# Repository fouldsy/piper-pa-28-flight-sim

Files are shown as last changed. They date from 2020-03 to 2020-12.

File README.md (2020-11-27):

# Piper PA-28 project

After many years of flight simming, I'm currently building a flight simulator using the cockpit from a 1975 Piper PA-28-151 interfaced to X-Plane 11 using AirManager.

For more information, see [the Piper PA-28 project website](https://fouldsy.github.io/piper-pa-28-flight-sim/index.html)

The following flight was taken over the San Juan Islands in X-Plane 11:

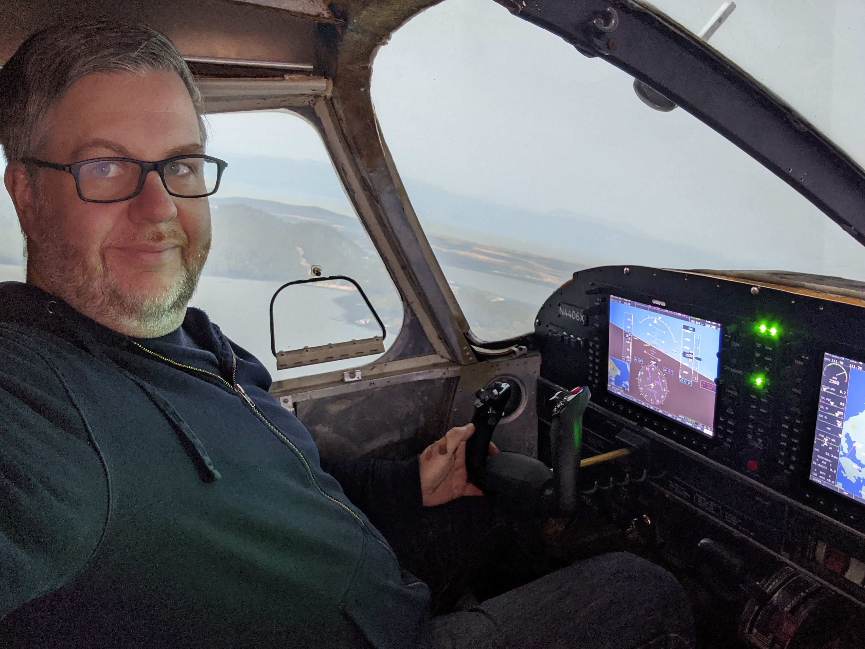
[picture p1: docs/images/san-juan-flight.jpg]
Flight over the San Juan Islands


Current view of the inside of the cockpit:

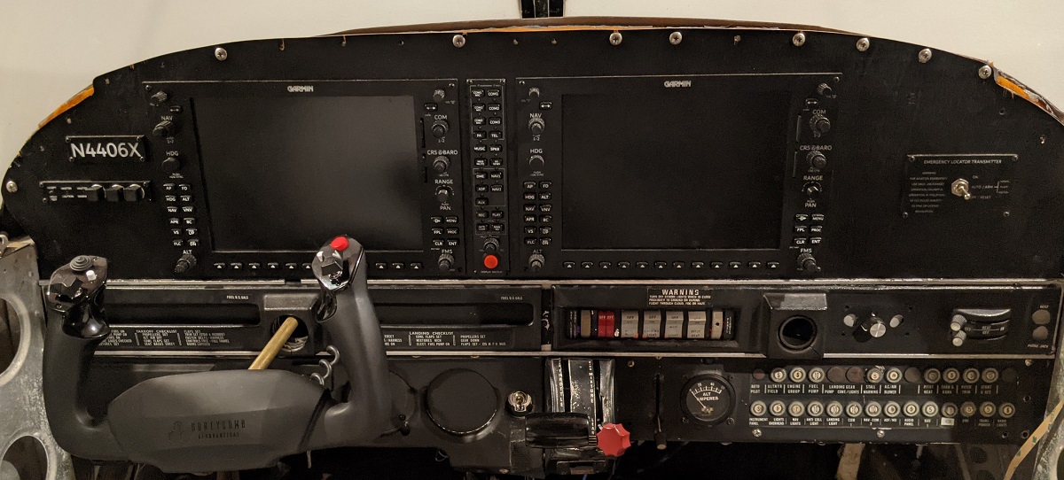
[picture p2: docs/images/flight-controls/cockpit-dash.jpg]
Inside the cockpit


Fully functional controls:

* Home made laser cut and 3D printed Garmin G1000 PFD, audio panel, and MFD
* Honeycomb Aeronautical Alpha yoke with shaft extension
* 3D printed fuel selector valve
* 5-position ignition switch

The following OEM hardware is also fully functional within the flight simulator:

* Switch panel
* Throttle and mixture controls
* Elevator trim wheel
* Flaps lever
* Parking brake
* Annunciator panel

Current view of outside of the cockpit:

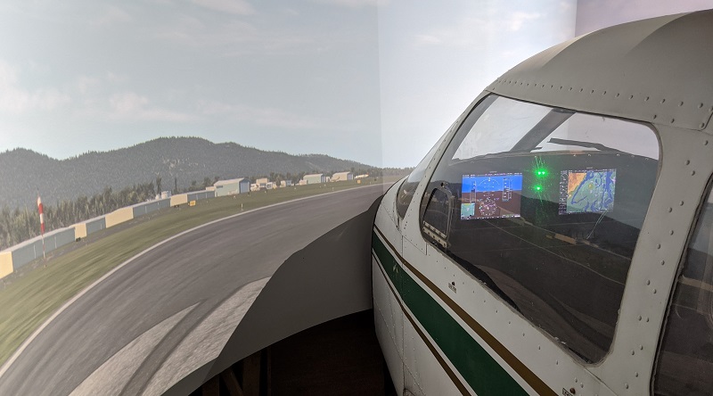
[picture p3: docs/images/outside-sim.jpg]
Outside the cockpit


The 12ft diameter 180 degree curved screen uses two Optoma GT1080 short-throw projectors warped using [Immersive Display PRO from  Fly Elise-ng](https://fly.elise-ng.net/immersive-display-pro/). The screen surface is painted a light grey.

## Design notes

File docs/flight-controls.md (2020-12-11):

# Flight controls

Where possible, I've tried to use OEM parts. The cockpit itself is a Piper PA-218-151, but I've given myself a little wiggle room since in X-Plane 11 I'm flying a PA-28-161.

Cockit panel

Associated 3D components for adapting the OEM flight controls at [https://www.thingiverse.com/thing:4681780](https://www.thingiverse.com/thing:4681780).

## Flight yoke

The primary non-OEM part in the whole cockpit (aside from the G1000 units) is the yoke. I looked at ways to use an OEM yoke with a home-built control system, or to retrofit an OEM yoke onto a commercial USB yoke.

In the end, I went with the [Honeycomb Aeronautical Alpha yoke](https://flyhoneycomb.com/collections/honeycomb-flight-sim-hardware/products/alpha-flight-controls). I like the idea of having some additional controls on the yoke that could be mapped into the game if I wanted to change the views or for ATC communication, etc.

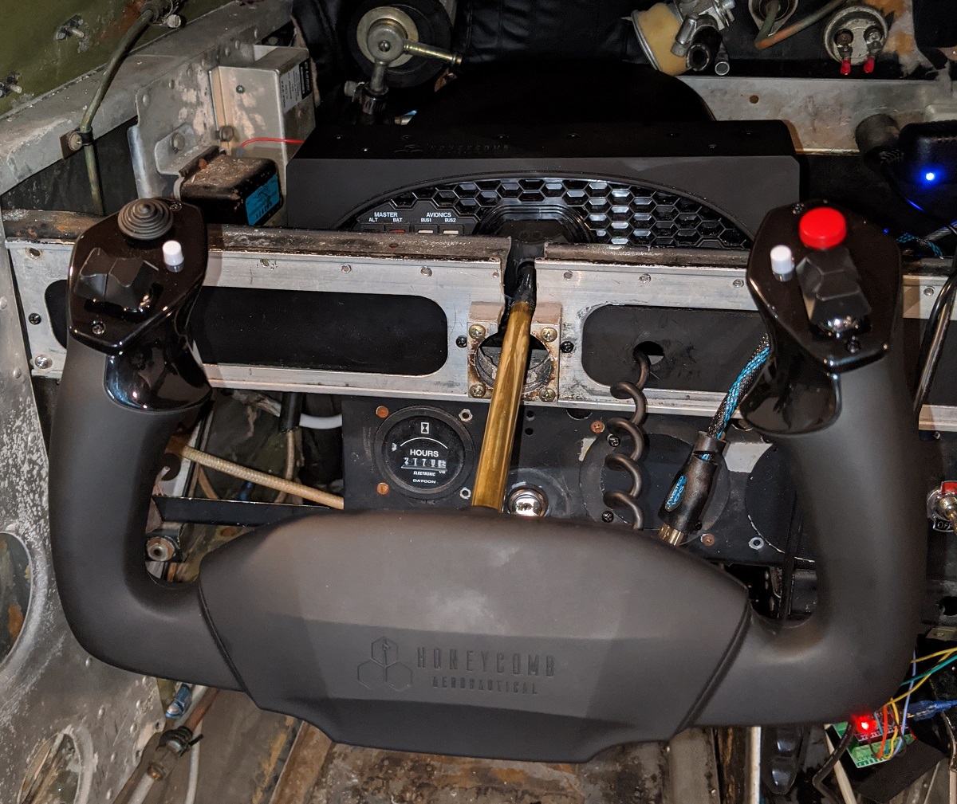
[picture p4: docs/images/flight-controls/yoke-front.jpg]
Extended shaft on Honeycomb Alpha yoke


The shaft of the yoke had to be extended for enough travel since it's mounted behind the panel. Without extending the yoke, my hands were so close to the G1000 units it was almost unusable. Thankfully, the Honeycomb yoke doesn't have wires that run through the shaft itself like some other yokes do. Instead, it's a solid steel shaft. I cut the steel shaft then used brass tube that I could slide over the existing steel shaft. This brass tube is glued with J-B Weld.

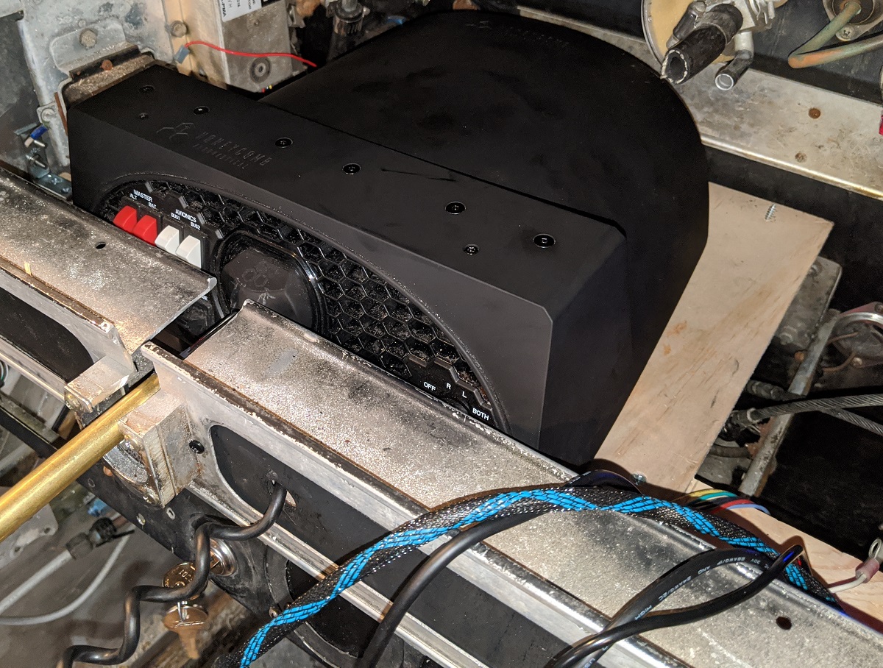
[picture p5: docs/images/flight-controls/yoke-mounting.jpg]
Mounting platform behind the dash for the Honeycomb Alpha yoke


Mounting the yoke was tough. There's very little room between the cockpit panel and the firewall, and the Honeycomb yoke only *just* fits in there. I made a platform for the yoke to attach to with its screw clamps. The platform is attached into the firewall and the sides of the cockpit with metal brackets.

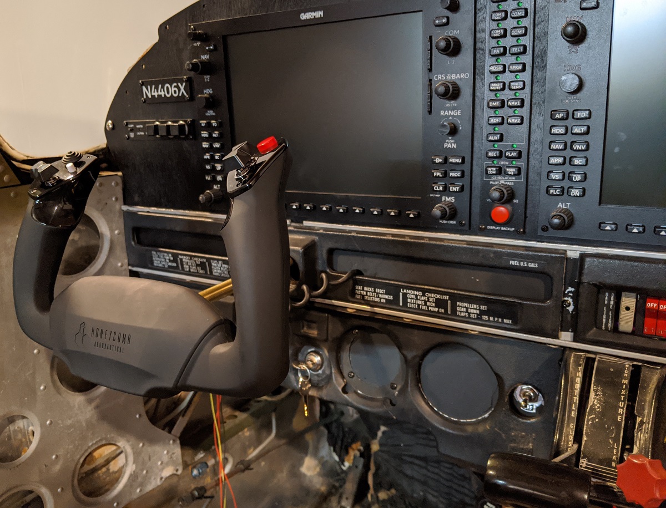
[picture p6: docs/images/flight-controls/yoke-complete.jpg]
Finished install of the Honeycomb Alpha yoke


Once all the panels are put back in place, it looks pretty good, and is solid enough that the yoke doesn't move around on the mounting platform. Yes, the switches and ignition on the Honeycomb yoke can't be used, but I have the real gear for that elsewhere in the cockpit anyway.

## Switch panel

The switch panel I don't *think* is from an actual PA-28-151, but it's mainly the exterior lighting controls that vary slightly between models. This is close enough for what I want.

All the original switches are used, though the wiring has been replaced to run through an Arduino Nano which then connects to Air Manager.

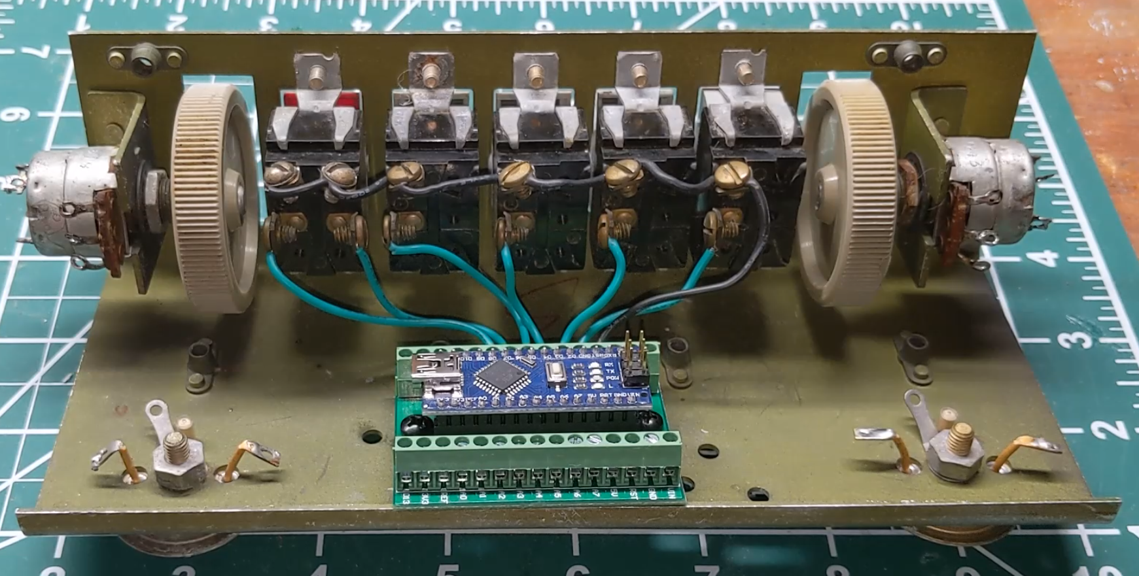
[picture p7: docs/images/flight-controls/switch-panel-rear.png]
Rear of the switch panel


The right-hand side rotating switch has also been connected to an LED strip controller (not shown in the photo) that will be used for the glare shield dash lights. A small circuit was included with the LED controller, so I rewired it from the built-in rotating switch to use this rotary knob on the switch panel. Works well. The LEDs are currently on the plastic spool ready for the glareshield to be built and installed, but the rotating switch does raise and lower the brightness of the LEDs.

## Throttle and mixture controls

The throttle and mixture levels were the first challenging OEM part I converted for use with the flight sim. Unlike a sliding potentiometer that could be used in Cessna flight sim, the Piper PA-28 use a rotating lever for both the throttle and mixture controls. These controls came with the cockpit, and I really wanted to use them.

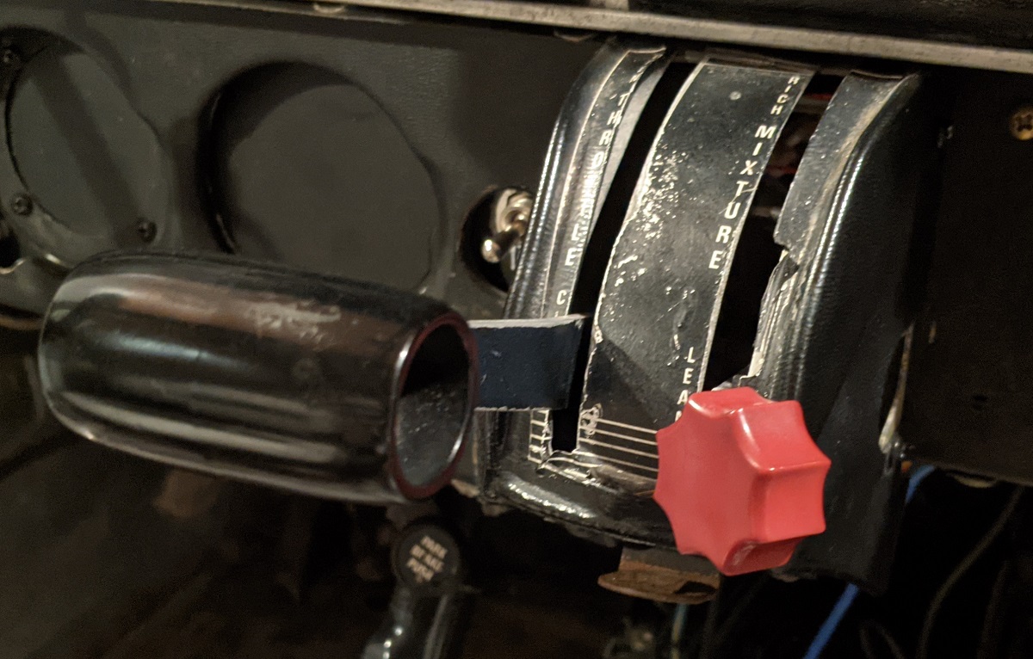
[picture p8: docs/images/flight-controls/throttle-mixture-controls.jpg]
Throttle and mixture controls


They work quite simply, after much thinking about ways to convert the motion for use with flight sim. The bolts for the levers were removed, and a potentiometer is attached to the metal brackets. The shaft of the potentiometer replaces the bolt, so the lever can continue to pivot. An adapter was designed and 3D printed that is glued to the lever and into the potentiometer. When the throttle or mixture lever moves, the potentiometer rotates with it.

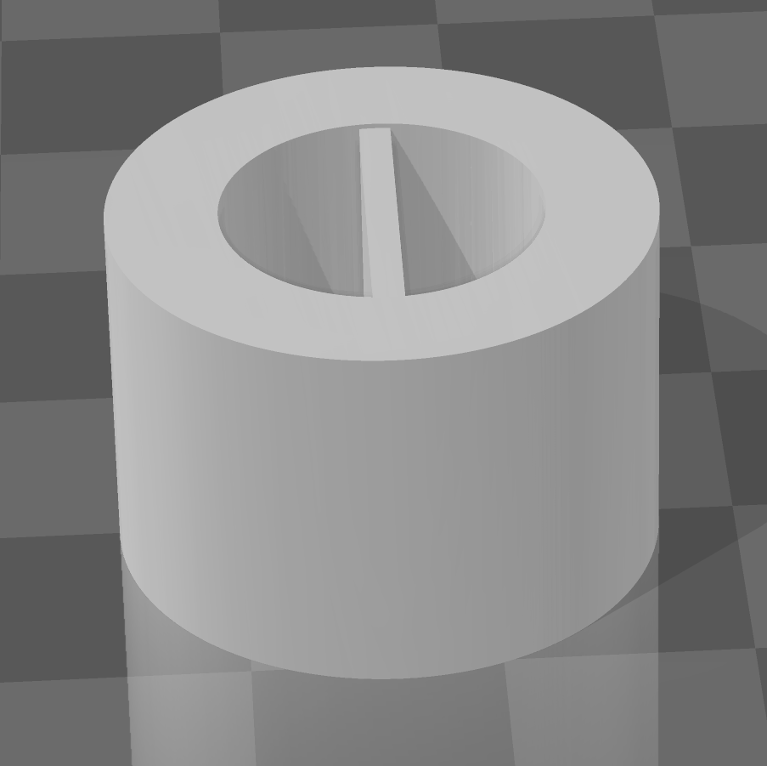
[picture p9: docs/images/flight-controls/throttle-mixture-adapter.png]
3D printed throttle and mixture adapter


As the potentiometer doens't move the whole range of motion, some math is done in Air Manager to multiply the potentiometer value into a ratio for use with the throttle and mixture controls. It doesn't give super precise change of throttle or mixture throughout the movement of a lever, but it's close enough for what I use in the flight sim.

## Flaps lever

The flaps lever was another challenging OEM conversion. Again, unlike a Cessna that has a flaps switch that's easier to model, the PA-28 uses a lever, similar to handbrake lever in a car. I worked through some ideas of trying to use contact points as the lever moved and locked into each position, but ended up with desiging and 3D printing an adapter for the end of the bolt that holds the lever in place.

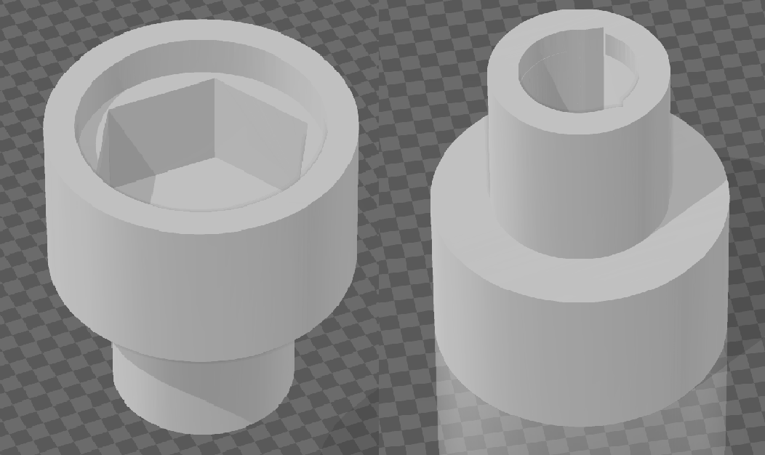
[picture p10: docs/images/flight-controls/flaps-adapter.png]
3D printed flaps lever adapter


The bolt was attached to the lever with JB Weld, rather than letting it simply be a pivot point. When the flaps handle is raised or lowered, the bolt rotates with it. The 3D printed adapter on the bolt head then turns a rotary encoder up or down accordingly. There's another 3D printed mount for the rotary encoder to attach it to the outside of the flaps lever base, which can be seen in the following photo:

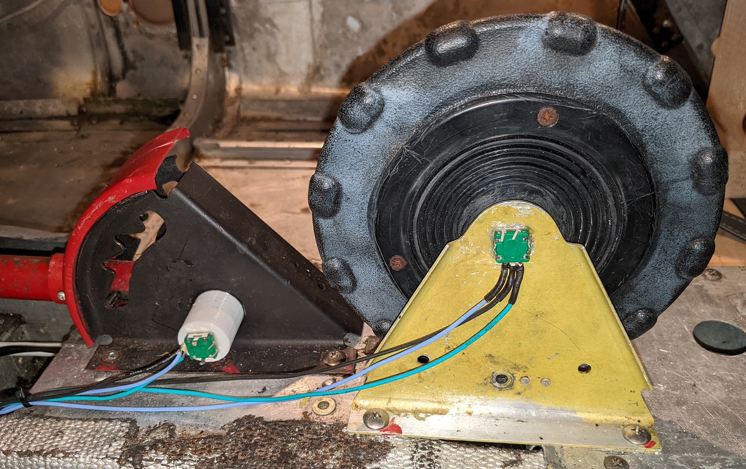
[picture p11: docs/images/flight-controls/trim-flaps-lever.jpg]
Flaps lever and trim wheel


The fun part was then translating this into positions of the flaps lever. There's some logic in the Air Manager Lua script that checks the time interval for the rotary encoder movement. Air Manager ignores rotary encoder changes for 1 second after the first motion.

What does this mean in practice?

* When you raise the flaps lever, the rotary encoder is first engaged.
* Air Manager sees the rotation, so raises the flaps in the flight sim.
* The flaps lever is physically locked in place and the rotary encoder stops moving.
* The raising of the flaps is one fluid motion, so Air Manager is waiting for a 1 second interval where the rotary encoder is now longer moving.
* At that point, Air Manager assumes any additional motion it detects is because you're again raising the flaps, or lowering them.

This all works well in practice, as you wouldn't typically raise flaps more than one notch at a time. The flight sim isn't detecting position 1, 2, or 3 for the flaps, rather it's just a flaps up or down command. When you land and are rolling out, I just need to make sure I lower one notch at a time with a couple of seconds break in between each lowering of flaps.

## Trim wheel

The trim wheel uses a similar approach as the throttle and mixture controls. A rotary encoder is used instead of a bolt, with the shaft of the rotary encoder inserted part way into the trim wheel. A 3D printed adapter is inserted through the rest of the trim wheel and glued in place so it rotates with the trim wheel. The adapter then causes the rotary encoder to turn as the trim wheel does.

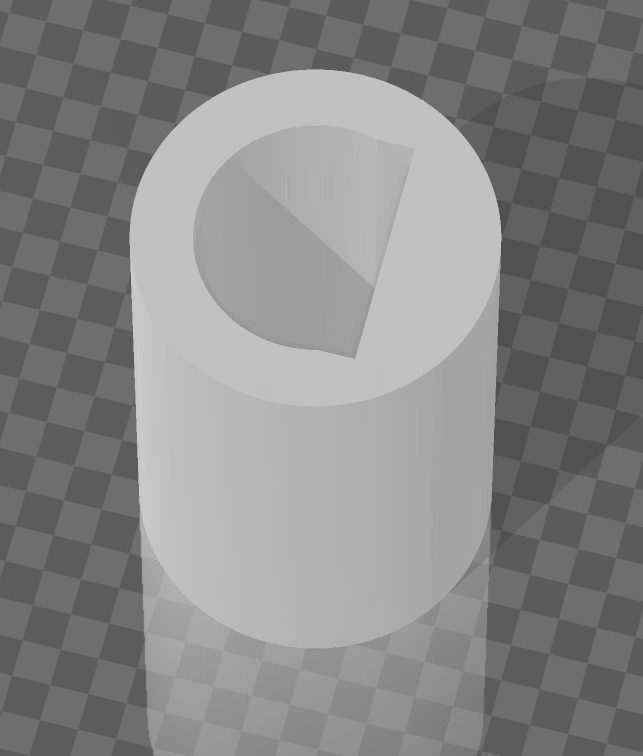
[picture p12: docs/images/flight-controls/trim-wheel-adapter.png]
3D printed trim wheel adapter


I had looked at 3D printing a trim wheel, as I found a suitable model online, but since almost everything else was OEM, I figured it made sense to get an OEM trim wheel, too.

Air Manager then trims the airplane up or down based on the rotary encoder motion. There's no additional logic required like with the flaps lever.

## Parking brake

The parking brake was the last thing I worked on. I tried a couple of different approaches, but came back to the tried and true approach of a 3D printed adapter on the bolt head to turn a potentiometer.

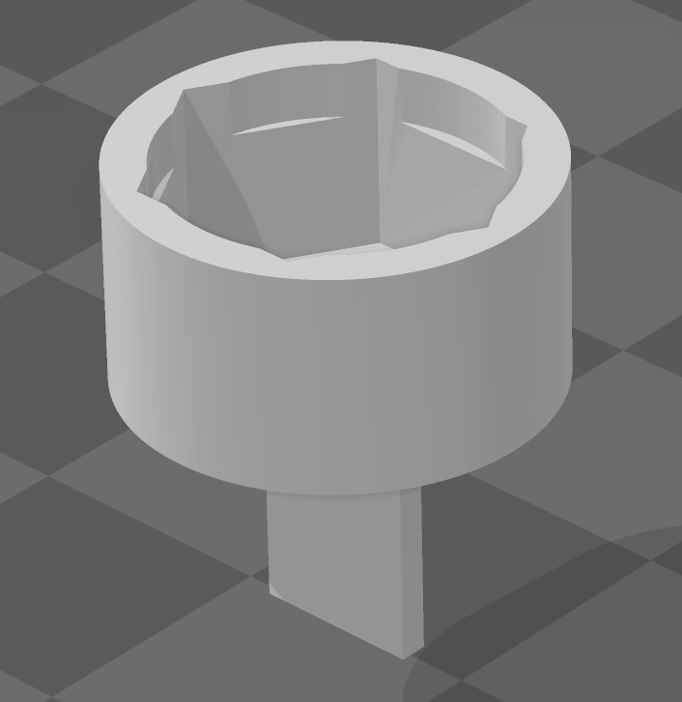
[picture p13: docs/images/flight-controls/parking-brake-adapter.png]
3D printed parking brake adapter


A hole is drilled through the shaft of the brake lever and bolt, with a metal pin inserted and glued with J-B Weld. As the brake lever rotates, the bolt also rotates, which turns the 3D printed adapter on the bolt head.

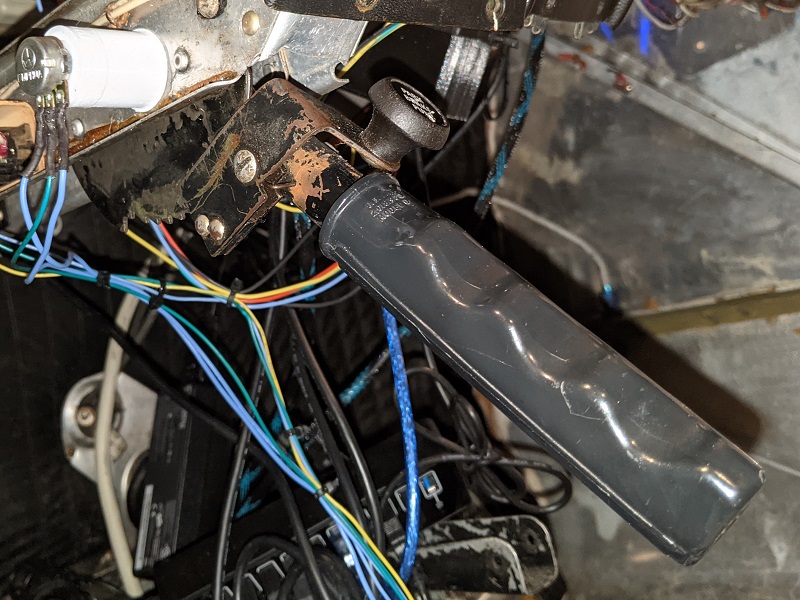
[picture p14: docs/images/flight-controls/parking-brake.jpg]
Parking brake lever with a rotary potentiometer


A potentiometer is then attached to the bolt head adapter. The movement is pretty slight, approximately *0.73* to *0.81* on a ratio scale of *0-1.0*, but it does at least translate the parking brake rotation into something Air Manager can recognize. 

An if statement in the Lua script then looks to see if the potentiometer value is below a certain threshold. If so, the parking brake is considered to be released. Above that thershold, it's engaged. I could have let it translate the movement into a ratio of brakes being engaged, but I wanted to keep it simple.

One challenge where was allowing the parking brake to lock in place. Originally I removed the brake cylinder, but that left no resistant on the lever for it to lock in place. So, the whole assembly is installed to add resistance and let the lever lock in place. This configuration also adds to the realism in an unintended way.

## Ignition switch

I looked at using an OEM ignition switch, but instead opted for a [Desktop Aviator](https://www.desktopaviator.com) 5-position keyed switch. The advantage, other than cost, was that it's designed to be easily wired in for the OFF-L-R-BOTH-START controls of the ignition switch.

The ignition switch is wired into an Arduino Nano which then connects to Air Manager.

## Fuel selector

The fuel selector is one of the only parts that's not OEM. I looked at ways to do it, but in end I found a [3D model online](https://www.cgtrader.com/3d-print-models/hobby-diy/mechanical-parts/piper-pa28-fuel-selector-for-flight-simulator) that was available to print. After spraying the fuel selector knob red, it looks pretty close to the real thing.

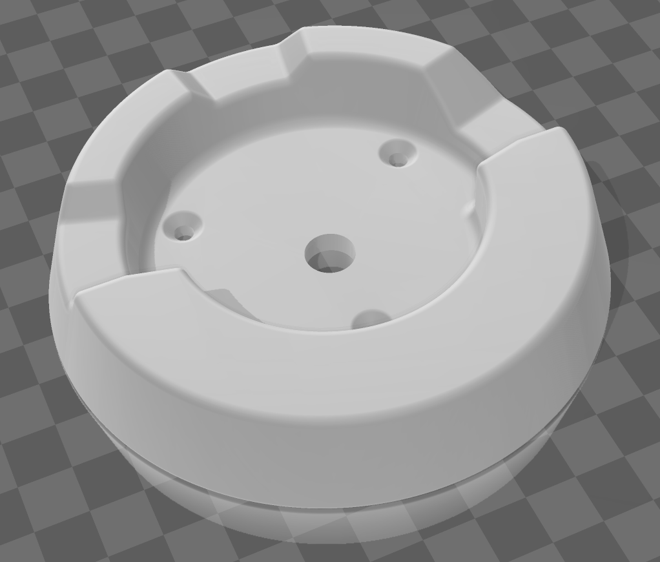
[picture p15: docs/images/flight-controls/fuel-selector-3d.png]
3D printed fuel selector controls


I still need to cut some vinyl labels and a black backing circle to cover the holes from trying to mount it, but it functions pretty well and again adds to the realism of switching left and right tanks at intervals during a flight.

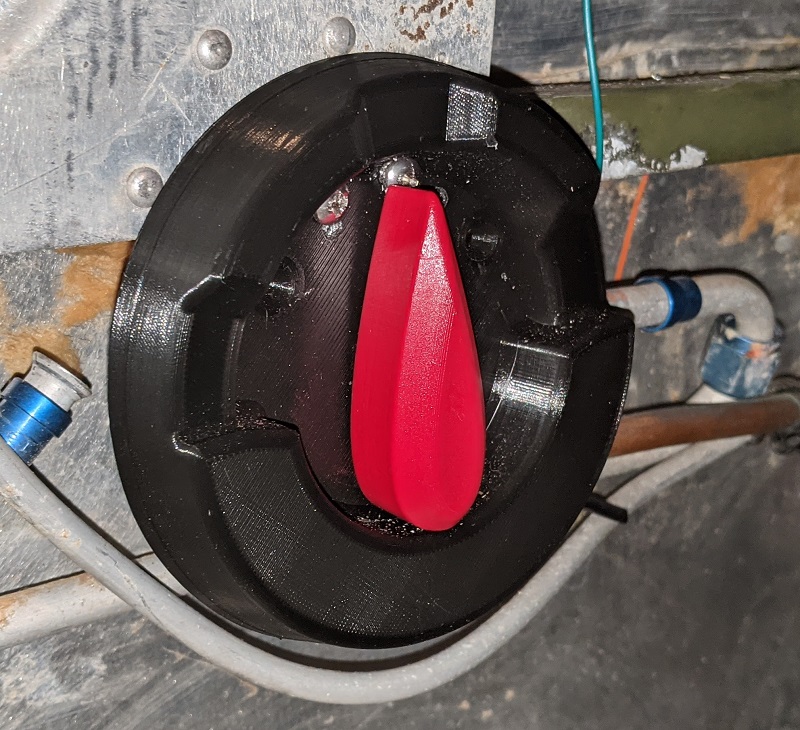
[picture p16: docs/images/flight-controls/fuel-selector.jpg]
3D printed fuel selector controls


The switch is an [industrial 3-position rotary switch](https://www.amazon.com/gp/product/B07MYM2GRX/), so has some clunk to it. It's a little large, but it's mounted down where the actual fuel lines (still) run in the cockpit, so there was clearance to mount it anyway.

## Annunciator panel

One interesting part of the original cockpit I wanted to put to use was the annunciator panel. Unfortunately, the G1000 PFD takes up a lot of space on the pilot side of the cockpit, so there wasn't really room for the OEM annunciator panel to fit.

Annunciator panel

Instead, I laser cut a custom panel that would somewhat go with a Piper PA-28 that had received a G1000 upgrade. The master caution and master warning lights and the accept / hold to test buttons all work in the flight sim. The OEM vaccum, alternator, and oil warning lights aren't connected and more just a visual nod to the original cockpit.

Laser cut custom annunciator panel

## ELT panel

One final thing I wanted to add was an emergency locator transmitter (ELT) panel. I haven't seen this actually modelled in X-Plane 11, but it's a fun little addition and breaks up the otherwise empty space on the co-pilot side of the cockpit panel.

The ELT is a laser cut panel with the actual wording from a Piper PA-28 ELT. The three-position switch then replicates the positions the ELT could be placed in. It's not wired up to anything, but looks neat and adds an extra step to simulate in the start-up and shutdown procedures.

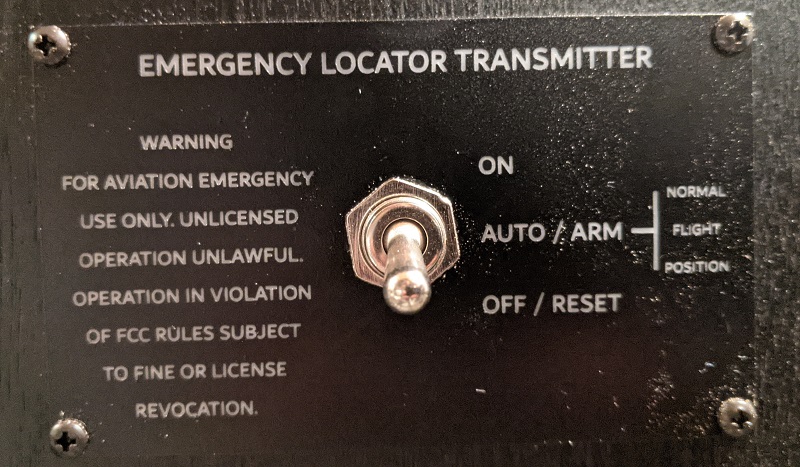
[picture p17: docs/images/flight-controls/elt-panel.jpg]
Laser cut ELT panel


I have looked at installing an OEM ELT panel, but visually I think it would look a little jarring next to the G1000 MFD. So, this is a balance between OEM look and a bit of an updated appearance. Since it functionally doesn't do anything anyway, I'm not sure the cost be worthwhile.

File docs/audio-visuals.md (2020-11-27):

# Audio and visuals

The cockpit is the focal point of the flight simulator, but the visuals are just as important to the whole look and feel.

The desktop PC that runs the flight simulator is as follows:

* Intel i7-10700k 8-core 3.8Ghz
* 32GB DDR4 3600
* EVGA nVidia GeForce RTX 2070 Super 8GB
* MSI MPG Z490 Gaming system board
* Samsung 970 EVO M.2 1TB
* WD Blue 3D NAND 1TB SSD
* Corsair iCUE H115i water cooling with 280mm radiator and dual 140mm fans

## Projectors

From the outset, I knew I wanted a minimum of two 1080p projectors to build a 180-degree curved screen. Two projectors is pushing the limits of a 180-degree screen, and I'd ideally like to add a third projector and extend to 220-degrees or more.

Currently, the flight sim uses two [Optoma GT1080 projectors](https://www.optoma.com/us/product/gt1080/) mounted to the ceiling.

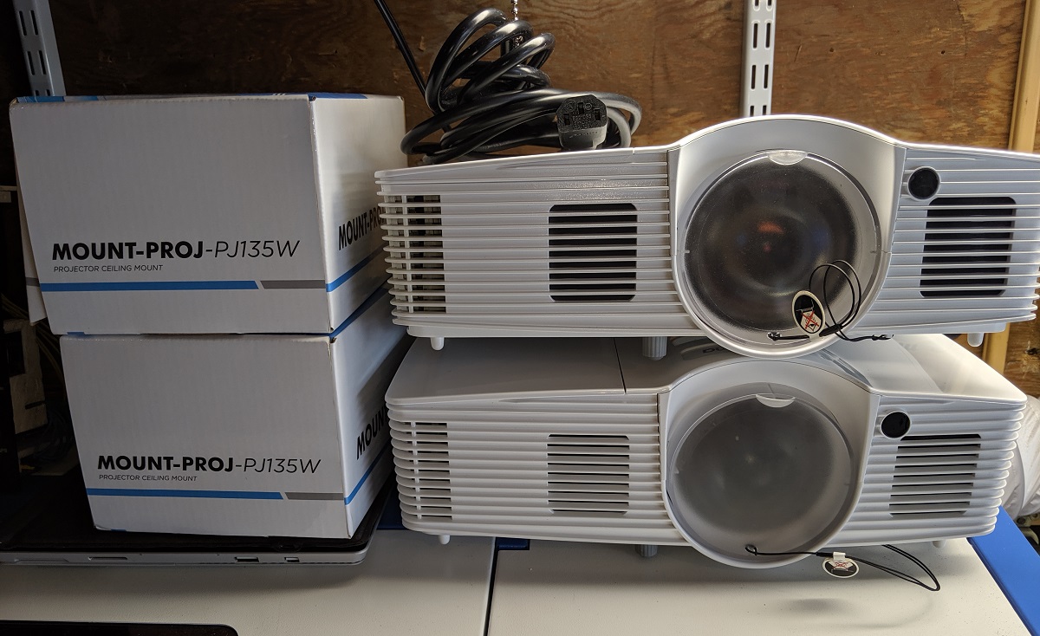
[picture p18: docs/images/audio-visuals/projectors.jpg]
Projectors and mounts


The projectors are mounted so that their images cross each other with a 15% or so overlap on the screens. So, the left projector is actually displaying the right-hand side of the curved screen, and the right projector is the displaying the left-hand side of the curved screen.

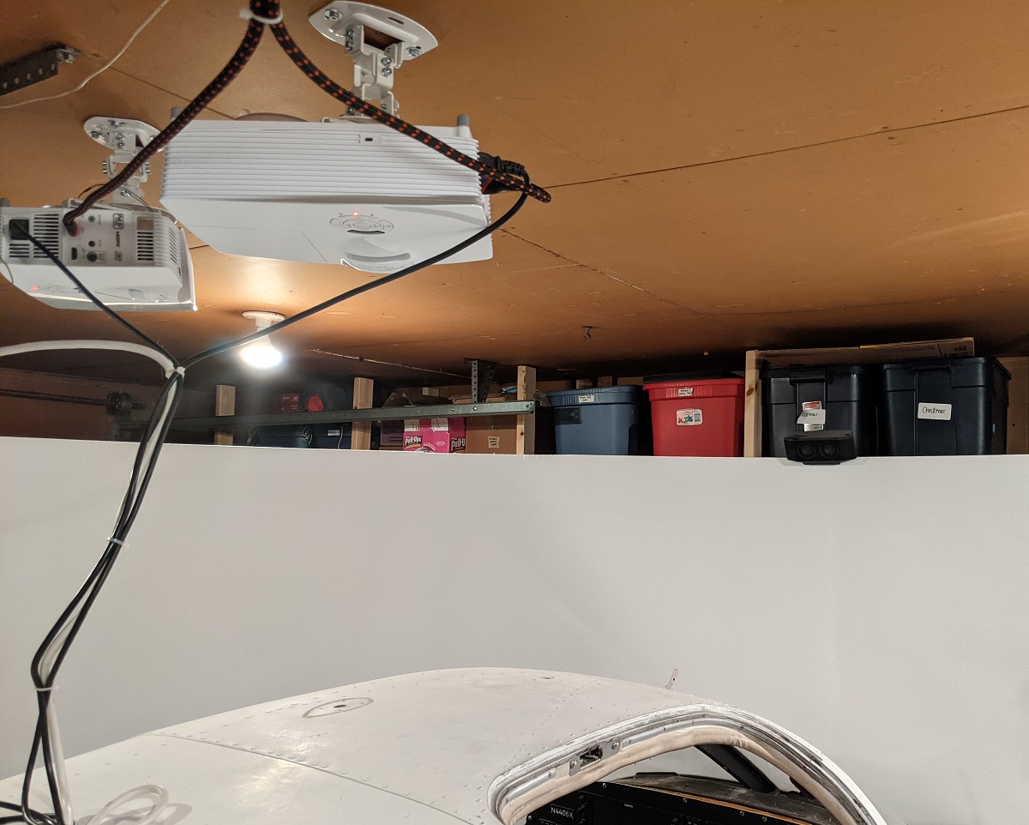
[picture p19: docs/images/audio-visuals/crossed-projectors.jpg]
Projectors mounted and crossing images


Both projectors then connect via HDMI cables to the desktop PC that runs the flight simulator.

## Curved screen

I can't take credit for the curved screen design. The [A-10 Warthog project had a video](https://www.youtube.com/watch?v=AsleWkgOsak) on how he built a cheap curved projection screen that I followed almost exactly. I built a 12ft diameter 180-degree curved screen that wraps around the cockpit. The size of the screen was based around the length of the cockpit to given a wrap-around perspective.

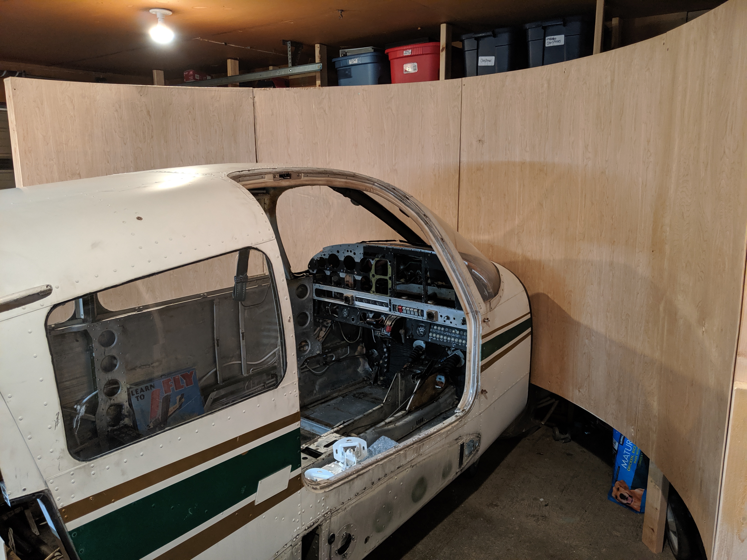
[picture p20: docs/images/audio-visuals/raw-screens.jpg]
Rough curved projection screen


The projection screen is raised 2ft off the ground, and the projection surface is 5 feet tall. With only using two projectors I don't quite fill all the space, but it's good enough for my uses. The projection screen was given a light skim coat of plaster to remove the wood grain texture and was then painted a light grey.

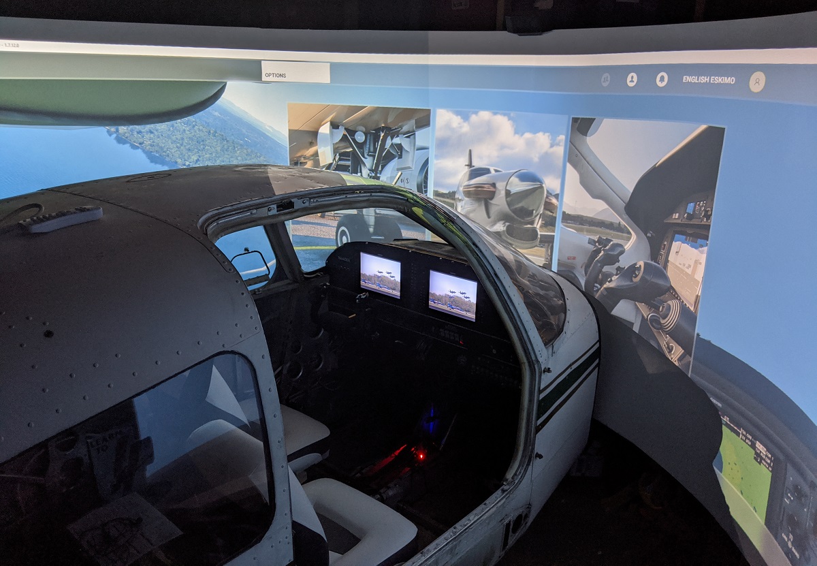
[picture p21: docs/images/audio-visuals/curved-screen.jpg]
Curved projection screen


## Audio

Top quality audio wasn't critical for me, but I have created an immersive system. I use an old [Logitech X-540 5.1 sound system](https://www.newegg.com/logitech-x-540/p/N82E16836121006) with the subwoofer mounted just outside the cockpit by the pilot side. The front speaker is mounted at the top of the curved projection screen in front of the cockpit, with the left and right speakers mounted on the side of the projection screen facing inwards at about seating height when inside the cockpit.

The Logitech controls are on the floor between the pilot and co-pilot seat, so I can turn the system on and off or adjust volume from the pilot seat. Although I don't have the rear speakers hooked up, it's still good immersion, and you can hear an airplane move across the speakers as it would pass across the screen.

Powering the audio is a [basic USB audio adapter](https://www.amazon.com/gp/product/B004HXGJ3S). I looked at using the desktop PC sound card, but that would involve running a lot more cables out to the flight simulator. The USB audio card works well, and gives me the option to plug in a headset for the pilot in the future if I want to try adding a little more immersion.

## Additional systems

A [10-port USB hub](https://www.amazon.com/gp/product/B076YN6CSG) in the cockpit lets me run [one long USB cable](https://www.amazon.com/gp/product/B000W0BVTW) back to the desktop PC that runs the flight sim. I can unplug this one USB cable to disconnect the whole cockpit when I use the PC for other games and I don't want the flight controls inteferring with anything.

The USB hub runs two Arduino Megas for the Garmin G1000 PFD and MFD, and then four Arduino Nanos for the G1000 audio panel and rest of the flight controls. The Honeycomb Alpha yoke and audio adapter are also connected via USB.

Finally, a [small backlight keyboard / mouse combo unit](https://www.amazon.com/gp/product/B07T13GLY3) gives me some amount of regular PC input when in the cockpit. This unit connects via a USB Bluetooth adapter connected to the USB hub. Ideally, this keyboard should only be needed to set up a flight. Everything else should be able to function using the actual flight controls in the cockpit.

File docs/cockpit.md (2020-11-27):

## The cockpit

The key part of the flight sim is, obviously, the cockpit :) The immersion of being inside an actual cockpit is quite something.

The flight sim is based on the following:

* **Aircraft:** 1975 Piper PA-28-151
* **Tail number:** N4406X
* **Serial number:** 28-7615012
* **Hobbs meter:** ~2070 hours

## Purchase and delivery

I'd originally been set on the cockpit for a Cessna 172, but price-wise, I was never able to find one that was within reach. I had no real attraction to the Piper PA-28 other than it's what I was able to finally find at a decent price.

There's a number of sellers out of Florida that seem to have GA fuselages for sale. Most are still considered airworthy, hence the price tag that goes with them.

I was able to find one that had been left sitting outside in te Florida sun and was no longer classed as airworthy. Most of the internal components were stripped and sold individually. The fuselage was available for $950 US.

I was able to have the seller cut the fuselage just behind cargo compartment. I didn't need the mid and tail-section. This helped cut down enormously on crating and shipping.

It took 2-3 weeks to freight it all the way from Florida to Seattle, and I don't have any pictures of it crated as we had to take it out the crate in the back of the delivery truck just to fit it on the lift gate and into the garage!

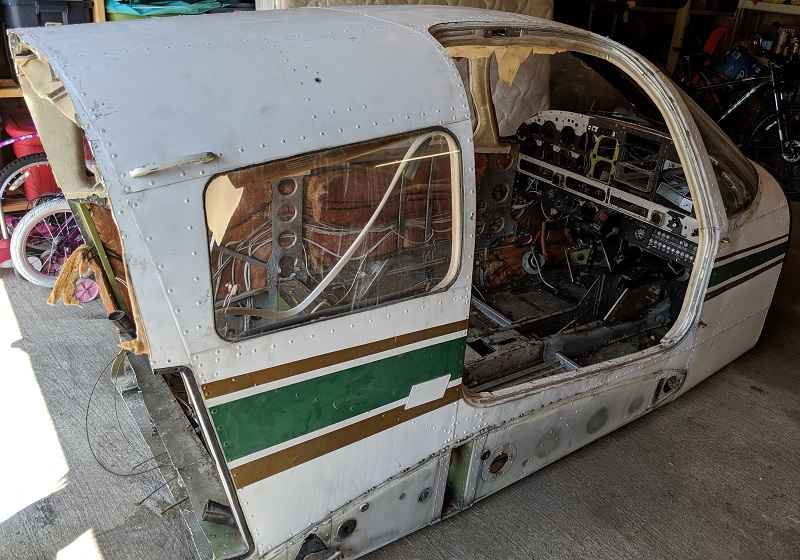
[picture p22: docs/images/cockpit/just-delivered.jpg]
Cockpit just delivered and in the garage


This was my first time seeing just what I'd let myself in for. The interior was a mess, which I could tell from the listing photos.

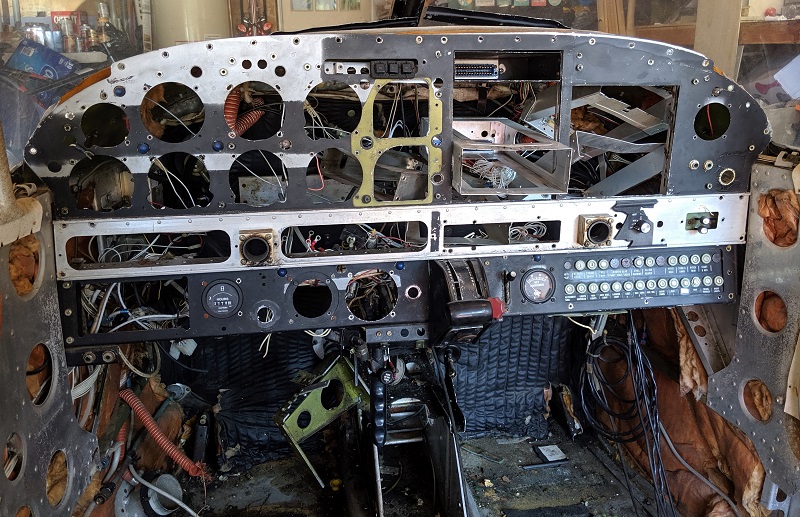
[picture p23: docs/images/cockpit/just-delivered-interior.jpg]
Inside the cockpit just after delivery


Most of the interior was soon to be ripped out anyway, along with most of the instrument panel.

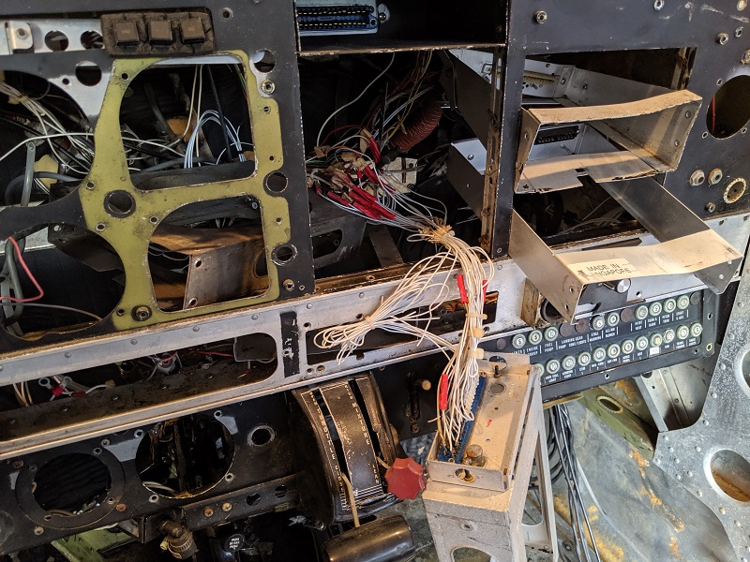
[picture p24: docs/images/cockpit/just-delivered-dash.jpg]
Instrument panel just after delivery


## Cleaning the interior

After assessing what the cockpit had and what was worth keeping, I then set about cleaning everything up. First, I removed all the old interior fabric, insulation, and coverings. It was surprising just how much there was to come out of a fairly stripped-down cockpit to begin with.

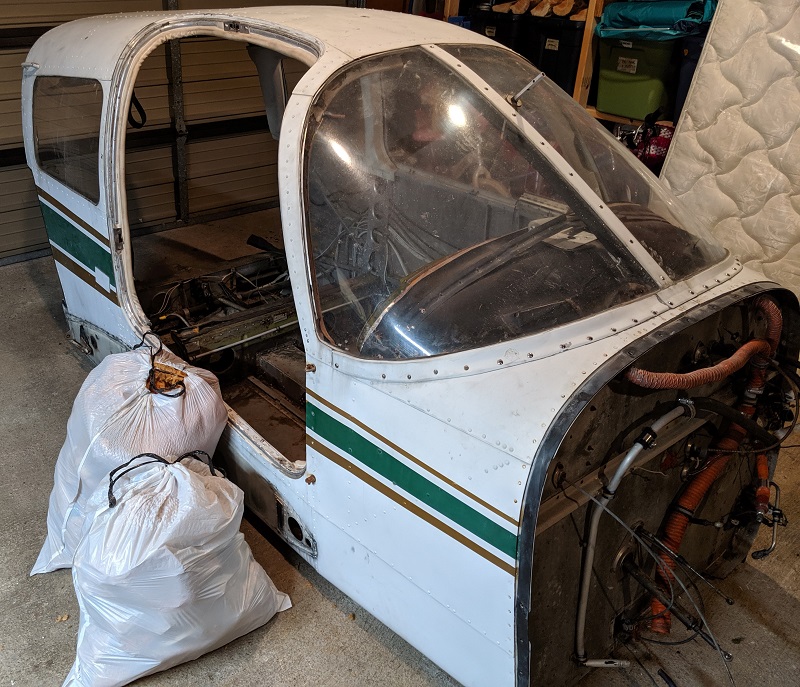
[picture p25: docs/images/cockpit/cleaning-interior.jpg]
Cleaning the interior of the cockput


There was also so much wiring and tubing throughout, most of which I wanted to remove to make it easier to clean and then route the flight sim components for USB, HDMI, power, etc.

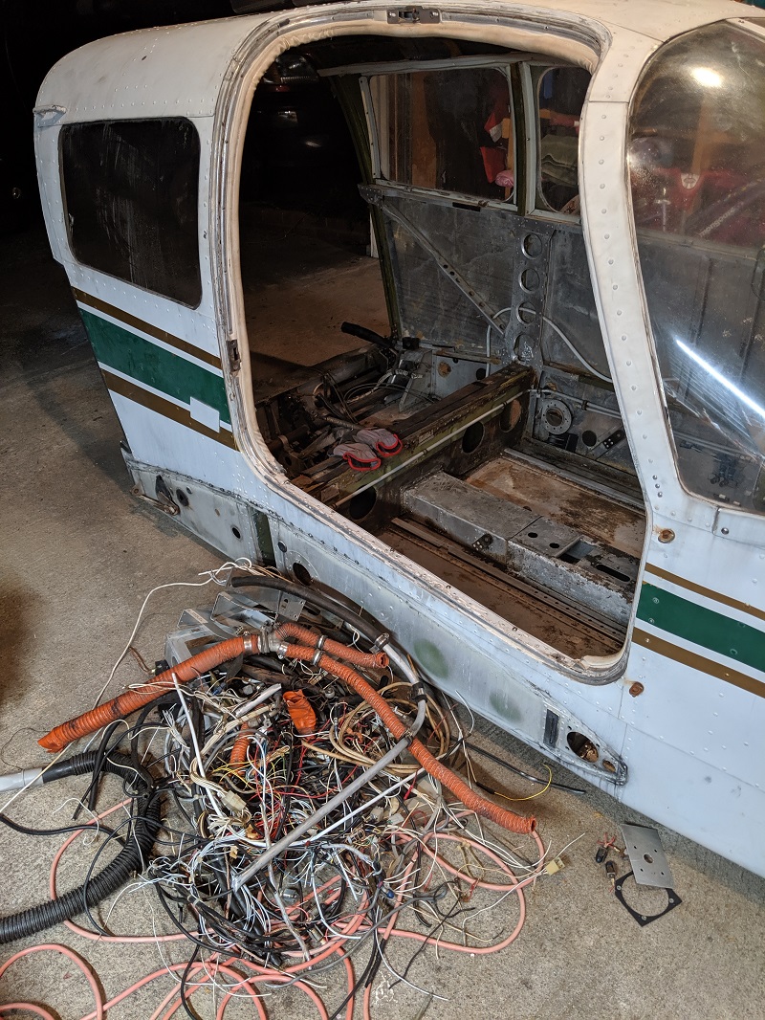
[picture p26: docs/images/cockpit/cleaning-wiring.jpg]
Removing all the old wiring and tubing


With almost everything stripped back to the bare metal, I could then clean up all the actual interior bodyframe and metal itself. This was time consuming and messy, but overall made it a much better starting point to crawl around inside of to install the flight sim components.

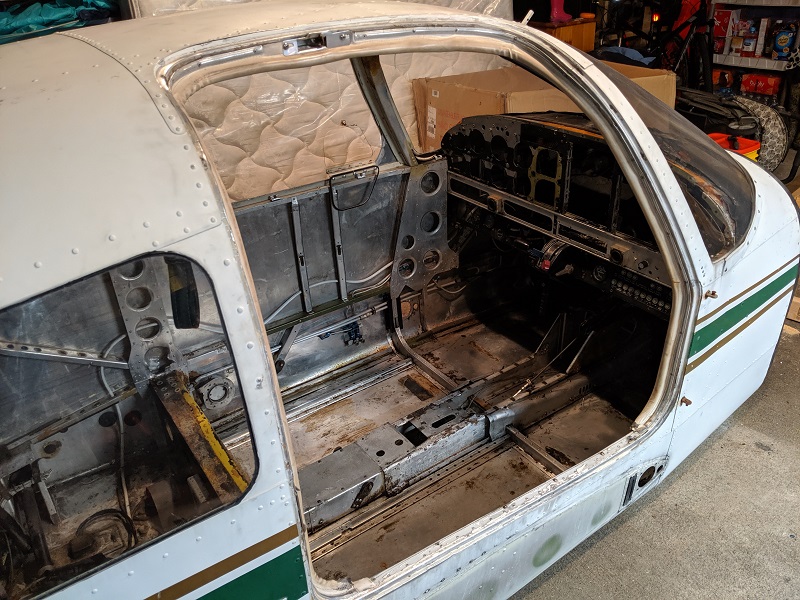
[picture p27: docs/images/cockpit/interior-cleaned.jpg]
Cockpit interior cleaned


I couldn't get everything out from behind the instrument panel without removing the entire panel, which while tempting, seemed a little unnecessary and too much work. But even like this, it gave a much better starting point to then begin building the flight simulator.

Instrument panel cleaned up and tidied

## Initial component installation

One of the main reasons I'd wanted a Cessna 172 cockpit was to use a Garmin G1000 suite. As much as there's an appeal to steam-driven gauges, since I can't fly for real, I've always been attracted to the G1000 panels.

Initially, I was going to stay true to steam-driven gauges, so built a Garmin GNS-430 and GNS-530 unit based on the designs by [Allan Glen](https://cessna172sim.allanglen.com/).

Laser cut and 3D printed Garmin GNS-430 and GNS-530 units

These units worked okay, and it was a great learning experience with the laser cutter, 3D printer, and Arduino wiring / Air Manager connections.

Garmin GNS-430 and GNS-530 units installed in instrument panel

By the time I was working on the Bendix King KT76C transponder and initial designs for 3D printed gauges using stepper motors, I realized that it wasn't really what I wanted.

Bendix King KT76C transponder

I was fine with the cockpit itself, but trying to remain true to the PA-28-151 just wasn't going to cut it. So, I explored X-plane models for the Piper PA-28 181 and similar that offered a G1000 suite, and [ended up building my own](g1000.md).

So, the cockpit is somewhat of a mix of a PA-28-151 in terms of the switch panel and instrument panel layout, but upgraded for a G1000 suite :) I don't think many real-world owners of a PA-28-151 would foot the bill for such an upgrade, but hey - it's my plane, so I can do it! I've still [incorporated a lot OEM equipment for flight controls into the flight sim](flight-controls.html).

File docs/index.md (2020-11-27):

# Piper PA-28 project

After many years of flight simming, I'm currently building a flight simulator using the cockpit from a 1975 Piper PA-28-151 interfaced to X-Plane 11 using AirManager.

The cockpit is capable of running Microsoft Flight Simulator 2020, but the current development tools don't provide the full functionality required for what I consider to be try flight-worthiness. Visually, it's very impressive.

The following flight was taken over the San Juan Islands in X-Plane 11:

Flight over the San Juan Islands

For more information, see [more about the cockpit](cockpit.md) or [building the Garmin G1000 suite](g1000.md).

Fully functional controls:

* Home made laser cut and 3D printed Garmin G1000 PFD, audio panel, and MFD
* Honeycomb Aeronautical Alpha yoke with shaft extension
* 3D printed fuel selector valve
* 5-position ignition switch

The following OEM hardware is also fully functional within the flight simulator:

* Switch panel
* Throttle and mixture controls
* Elevator trim wheel
* Flaps lever
* Parking brake
* Annunciator panel

See how I've [incorporated a lot OEM equipment for flight controls](flight-controls.html).

Current view of outside of the cockpit on runway 20 at Bremerton National (KPWT):

Outside the cockpit

The 12ft diameter 180 degree curved screen uses two Optoma GT1080 short-throw projectors warped using [Immersive Display PRO from  Fly Elise-ng](https://fly.elise-ng.net/immersive-display-pro/). The screen surface is painted a light grey.

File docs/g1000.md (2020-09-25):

# Garmin G1000 suite for flight simulator

Back in my early days of seriously getting in flight simulator and starting to build panels around 2006, the idea of building a Garmin G1000 unit simply wasn't feasible. With the advent of consumer-grade 3D printers and laser cutters, that's now a reality.

Finished G1000 instrument panel

Close-up G1000 instrument panel

This project draws heavy inspiration from [Allan Glen's C172 Garmin GNS430 and GNS530 units](https://cessna172sim.allanglen.com/). I started down that route for my own home cockpit (a 1975 Piper PA-28-151 fuselage).

Complete G1000 instrument panel

Please read through all this before you get started. There's a lot of pieces to laser cut, 3D print, engrave, and assemble. I use Air Manager and X-Plane 11, but there's no reason this shouldn't work with other flight sims or controllers. I'm eagerly awaiting FS2020 to see!

* [Thingiverse project files](https://www.thingiverse.com/thing:4172029)
* [GitHub project files](https://github.com/fouldsy/piper-pa-28-flight-sim)

## Parts required

The following parts and components are required to build the G1000 units. The 10.4" LCD screens and then dual rotary enconders are the most expensive components. In total, this entire G100 was under $450 US, which is a whole lot less than commercial offerings, or even kit options. Even adding in the cost of a 3D printer and laser cutter, it's under $1,000 US.

### Panel components

The following items are needed to cut, attach, and finish the panels:

| Item | Dimensions | Quantity | Purchase |
|---|---|---|---|
| 5mm cast white acrylic | 12" x 8" | 4 | |
| Pan head machine screws | #6-32 x 3/8" | 20 | [https://www.amazon.com/gp/product/B00F359CIS](https://www.amazon.com/gp/product/B00F359CIS) |
| Matt black spray paint | 12oz | 1 | |

### Screens, power, and HDMI

The following LCD screens and components are needed for the G1000 PFD / MFD units:

| Item | Quantity | Purchase |
|---|---|---|
| 10.4" LCD screen @ 1024x768 | 2 | [https://www.amazon.com/gp/product/B07R3RZC4F](https://www.amazon.com/gp/product/B07R3RZC4F) |
| 12V 2A power adapter | 2 | [https://www.amazon.com/gp/product/B00Q2E5IXW](https://www.amazon.com/gp/product/B00Q2E5IXW) |

### Hardware components

The following associated buttons, switches, and Arduinos are needed to actually run the suite of devices:

| Item | Quantity | Use  | Purchase |
|---|---|---|---|
| Arduino Mega 2560 | 2 | PFD / MFD wiring | [https://www.amazon.com/gp/product/B01H4ZDYCE](https://www.amazon.com/gp/product/B01H4ZDYCE) |
| Square 7mm x 7mm momentary mini push button | 85 | Panel buttons | [https://www.amazon.com/gp/product/B00OK476IG](https://www.amazon.com/gp/product/B00OK476IG) |
| 5mm dual rotary encoder with push button switch | 11 | NAV, COM, ALT, CRS/BARO, FMS, dummy audio | [https://www.propwashsim.com/store/dual-encoder-kit](https://www.propwashsim.com/store/dual-encoder-kit) |
| 6mm rotary encoder with push button switch | 2 | HDG control | [https://www.amazon.com/gp/product/B0177VGSQY](https://www.amazon.com/gp/product/B0177VGSQY) |
| 6mm rotary potentiometer | 4 | Dummy PFD / MFD volume control | [https://www.amazon.com/gp/product/B07DS5C7RF](https://www.amazon.com/gp/product/B07DS5C7RF) |
| 4-way directional switch with rotary encoder and push button | 2 | PFD / MFD range and pan control | [https://www.mouser.com/ProductDetail/ALPS/RKJXT1F42001?qs=6EGMNY9ZYDTsBzSTrhiL0w%3D%3D](https://www.mouser.com/ProductDetail/ALPS/RKJXT1F42001?qs=6EGMNY9ZYDTsBzSTrhiL0w%3D%3D) |
| Arduino Nano | 1 | Audio panel wiring | [https://www.amazon.com/gp/product/B07G99NNXL](https://www.amazon.com/gp/product/B07G99NNXL) |
| 15mm momentary red push button switch | 1 | Audio panel emergency flip | [https://www.amazon.com/gp/product/B019DSZQ9O](https://www.amazon.com/gp/product/B019DSZQ9O) |

## Make the G1000 faceplate

The PFD and MFD faceplates are each cut from 5mm cast white acrylic. A piece of acrylic cut to 12" x 8" works great. The cut-out section for the screen provides enough material to then cut out the required parts for the audio panel.

The `laser_cut/1000-faceplate.svg` file includes three layers - *vector*, *bevel*, and *engrave*. Use the *vector* layer to cut the outline for the faceplate. Without removing the piece of acrylic, then use the *bevel* layer to raster engrave the lines for the soft-key buttons.

Remove the faceplate from the laser cutter, pop-out the cut pieces for the buttons or screen holes, then remove any backing paper if needed. Use an alcohol cleaner to clean at least the front of the acrylic, as this is sprayed in the next step. You want to remove any residue left over from the laser cutting or protective film / paper.

Use a black spray paint (I used a matt finish) to spray the front of the faceplate. Use multiple light coats, and take care to minimize any dust in the spray area. Make sure the edges of the panel, button holes, and inside of the screen cut out are also sprayed black.

When the spray paint is dry, place a scrap piece of thin plywood in the laser cut, load the `laser_cut/g1000-faceplate.svg` file, and enable the *vector* layer. At a low power and high speed, vector cut this outline onto the plywood - it won't cut all the way through, but leaves a visible outline.

Carefully align the acrylic faceplate over the top of the etched outline on the plywood. If needed, use painters tape to hold in place. View the *engrave* layer, then raster engrave the faceplate to remove the layer of black spray paint and expose the white acrylic underneath for the lettering and graphics.

Etched faceplate

To protect the faceplate, lightly spray the faceplate with a clear matt protectant coat.

Repeat the process to create two such faceplates - one for the PFD, and one for the MFD.

## Make the G1000 hardware layer

The G1000 hardware layer is laser cut from the `laser_cut/g1000-hardware-mount.svg` file. As a suggestion, use the `laser_cut/kerf_test.svg` file to cut a single 7mm x 7 mm square in a piece of scrap acrylic. Test mount one of the momentary push button switches to see how snugly they fit. If they're too tight to push-fit into the acrylic, slightly increase the hole size and create another test cut. You want them just large enough to be able to gently push in place. If you need to update the size of the test hold, apply this updated measurement to the actual `laser_cut/g1000-hardware-mount.svg` file.

Once the hardware layer is cut from the acrylic, push fit the 7mm x 7mm momentary push button switches. A small spot of glue on each side of the switch holds them in place. This approach removes the need for PCB for the button mounts. Take care not to break the thin top strip like I did in this demo unit :)

Buttons attached

The rotary encoder, dual rotary encoders, potentiometers, and 4-way switch are mounted to the rear of the faceplate (next section). They don't actually attach to the hardware layer due to the length of the shafts of those components and the thickness of the acrylic.

Repeat the process to create two such faceplates - one for the PFD, and one for the MFD.

## Attach the G1000 layers

The `laser_cut/g1000-electronics-mount.svg` file is used to attach the Arduino Mega 2560 and LCD driver board. Cut out this file on the laser cutter, then use #6-32 x 3/8" pan head machine screws or adhesive like Weld-On to attach the electronics mount to the back of the hardware mount.

Use #6-32 x 3/8" pan head machine screws to then attach the Arduino Mega 2560 and LCD driver board to the electronics mount.

Electronics layer attached

Set the 10.4" LCD screen into place on the rear of the faceplate, then align the hardware mount and buttons with the faceplate. The buttons should be aligned in the center of the holes cut into the faceplate. The are two ways to attach hardware mount to the rear of the faceplate:

* Using #6-32 x 3/8" pan head machine screws
    * Carefully drill a shallow hole into the rear of the faceplate for the four hardware mount screws, then attach the two panels together.
* An arcylic-safe glue such as Weld-On
    * Follow the directions for your adhesive and attach the panels together.

I've tried both methods and prefer the accuracy of glueing the panels together. With needing to drill shallow holes in the rear of the faceplate to align with your buttons, it's easy to get that slightly offset and ruin the alignment.

All layers attached and LCD screen in place

3D print four copies of `3d_print/screen_clips.stl` and attach to the rear of the hardware mount to hold the LCD screen in place. The clips can be screwed or glued in place. Depending on where you mount the screen clips or actual screen you use, you may need a pair of the slightly shallower `3d_print/screen_clips_1mm.stl`.

Repeat the process to attach the layers - one for the PFD, and one for the MFD.

## Attach additional G1000 controls

With the hardware layer and faceplate joined using screws or adhesive, now attach the remaining controls to the faceplate. The following controls attach directly to the faceplate:

* Dual rotary encoders
* 6mm rotary encoder with push button (HDG control)
* 6mm rotary potentiometer (dummy VOL controls)
* 4-way directional switch with rotary encoder and push button (RANGE / PAN controls)

Depending on the controls you purchase, you may be able to use a nut and washer to attach to the shaft through the faceplate. If there's not enough length on the shaft to do this, you can use an adhesive to attach them.

Make sure you align the 4-way directional switch with rotary encoder up / down / left / right controls such that they correctly move horizontally and vertically.

Repeat the process to attach additional controls - one for the PFD, and one for the MFD.

## Wire up all the G1000 controls

Now the fun (?!) part. Wire up the all the controls to the Arduino Mega 2560. For ease of wiring, use a common ground around the outside of the hardware layer to the 7mm square push buttons. You can also then use this common groud for the all the rotary controls.

Color coding of wires may help to keep track of the wiring as you go. The Arduino Mega 2560 is almost completely full, so there's a lot of wires to solder and then connect. Keep track of what controls attach to which pin. I found it helped to configure Air Manager with the appropriate pins as I wired them up, even though the Arduino Mega 2560 wasn't connected.

Complete wiring

When all the controls are wired up, connect the delicate video cable from the LED driver board. Take care when you attach the video cable so as not to damage it.

The 4-way directional switch with rotary encoder and push button is "fun" to wire. In the following image:

* The blue wire is common ground
* The two red wires are encoder up and down
* The four green wires are directional
* The yellow wire is center push button

4-way joystick wiring

Repeat the process to wire up the controls - one for the PFD, and one for the MFD.

## 3D print G1000 buttons and knobs

There are two different buttons for the G1000 unit. I suggest printing a few extra of each button to allow for spares when engraving:

* `3d_print/button_small.stl` buttons are for the 12 multi-purpose buttons across the bottom of the unit.
* `3d_print/button_medium.stl` buttons are for the 20 autopilot, FMS, and radio controls.

Print these buttons in white PLA. I enable ironing so the top of the buttons are smooth and minimize the need for sanding. Once printed, apply a few light coats of black spray, the same as when doing the faceplate.

Once the paint is dry, use the appropriate `engrave/g1000_button_small_engrave.svg` or `engrave/g1000_button_medium_engrave.svg` to laser engrave the button text. Use a scrap piece of wood to quick cut a low-power outline of the button, align the 3D printed button into the outline, then raster engrave each text layer. Hide and view the next layer in the SVG file each time to work your way through the text layers for the `_medium` buttons.

Engraving buttons

To protect the buttons, lightly spray them with a clear matt protectant coat.

Print the knobs in black PLA. There's no engraving of text to do on them:

* `3d_print/knob_heading.stl` - print 1 of these.
* `3d_print/knob_range_pan.stl` - print 1 one of these. Note that supports are needed for the buttom of the knob.
* `3d_print/knob_volume.stl` - print 2 of these for the dummy COM / NAV volume controls.

3D printed range knob

For a little extra detail, print in black PLA two of `3d_print/dummy_sd_card.stl`. These can then be glued into place in the SD card slots of the faceplate.

Repeat the process to 3D print and engrave the buttons and knobs - one for the PFD, and one for the MFD.

## Attach G1000 buttons and knobs

The 3D printed knobs should all push-fit onto their respective knobs. You don't need to glue these in place.

Use the knobs included with the dual rotary encoders as they're already made to fit each of the shafts.

Attach the 3D printed buttons by placing a small drop of glue on the shaft of the 7mm square buttons then placing the appropriate engrave button on top. I take care not to push down on the button to avoid potentially pushing any glue into the button mechanism. The buttons should just need a little alignment to make sure they glue and dry flat and square.

Complete unit

Repeat the process to attach the buttons and knobs - one for the PFD, and one for the MFD.

## G1000 connections and configuration

The LCD screen recommends a 12V 2A power supply and connects using a regular HDMI cable. No special drivers should be required as it should display as a regular additional monitor.

The Arduino Mega 2560 connects using a USB A-B cable. Depending on the software you use to connect to your flight sim of choice, you may need to load their software onto the Arduino board first. For example, in Air Manager (which is what I use), you run the **Air Manager Arduino installer** to prepare the board for use with the Air Manager software.

If you use Air Manager, the `instruments/` folder contains the following LUA files:

* `pfd/logic.lua` for the primary flight display (the pilot side).
* `mfd/logic.lua` for the multi-function display (the co-pilot side).
* `audio/logic.lua` for the audio panel, although only a subset of controls are actually configured based on availability within X-Plane (I assume P3D has similar limited functionality).

These LUA files can be loaded into Air Manager, and then simply select the channel you configured your Arduino Mega 2560 on and then the actual analog or digital pin for each control. The following table outlines how I configured my pins and controls, but yours may vary:

| Type | Name | Pin |
|---|---|-----|
| Button | NAV flip flop | D13 |
| Rotary encoder - pin A | NAV outer rotary control | D12 |
| Rotary encoder - pin B |  | D11 |
| Rotary encoder - pin A | NAV inner rotary control | D10 |
| Rotary encoder - pin B | | D9 |
| Button | NAV 1/2 (push) | D8 |
| Rotary encoder - pin A | HDG rotary control | D6
| Rotary encoder - pin B | | D7 |
| Button | HDG sync (push) | D5 |
| Button | Autopilot | D4 |
| Button | Flight director | D3 |
| Button | Autopilot HDG | D2 |
| Button | Autopilot ALT | D14 |
| Button | Autopilot NAV | D15 |
| Button | Autopilot VNAV | D16 |
| Button | Autopilot approach | D17 |
| Button | Autopilot backcourse | D18 |
| Button | Autpilot vertical speed | D19 |
| Button | Autopilot flight level change | D21
| Button | Autopilot nose up | D20 |
| Button | Autpilot nose down | D22 |
| Rotary encoder - pin A | Altitude outer rotary control | D23 |
| Rotary encoder - pin B | | D24 |
| Rotary encoder - pin A | Altitude inner rotary control | D25 |
| Rotary encoder - pin B | | D26 |
| Button | Softkey 1 | D27 |
| Button | Softkey 2 | D28 |
| Button | Softkey 3 | D29 |
| Button | Softkey 4 | D30 |
| Button | Softkey 5 | D31 |
| Button | Softkey 6 | D32 |
| Button | Softkey 7 | D33 |
| Button | Softkey 8 | D34 |
| Button | Softkey 9 | D35 |
| Button | Softkey 10 | D36 |
| Button | Softkey 11 | D37 |
| Button | Softkey 12 | D38 |
| Button | COM flip flip | A0 |
| Rotary encoder - pin A | COM outer rotary control | A7 |
| Rotary encoder - pin B | | A6 |
| Rotary encoder - pin A | COM inner rotary control | A5 |
| Rotary encoder - pin B | | A4 |
| Button | COM 1/2 (push) | A3 |
| Rotary encoder - pin A | CRS rotary control | A12 |
| Rotary encoder - pin B | | A11 | 
| Button | CRS sync (push) | A8 |
| Rotary encoder - pin A | Barometer rotary control | A10 |
| Rotary encoder - pin B | | A9 |
| Button | Pan up | D50 |
| Button | Pan right | D51 |
| Button | Pan down | D52 |
| Button | Pan left | D53 |
| Rotary encoder - pin A | Range rotary control | A15 |
| Rotary encoder - pin B | | A14 |
| Button | D-> | D49 |
| Button | Menu | D48 | 
| Button | Flight plan | D47 |
| Button | Procedures | D46 |
| Button | Clear | D45 |
| Button | Enter | D44 |
| Rotary encoder - pin A | FMS outer rotary control | D42 |
| Rotary encoder - pin B | | D43 |
| Rotary encoder - pin A | FMS inner rotary control | D40 |
| Rotary encoder - pin B | | D39 |
| Button | FMS cursor (push) | D41 |

Repeat the process to connect and configure the panel in software - one for the PFD, and one for the MFD.

## X-Plane 11 G1000 bezel-less display

For X-Plane 11, when you pop-out the G1000 PFD and MFD and drag the displays to the LCD screens, a bezel is displayed around the device. To only view the actual screen component, copy and paste the the following files:

* `cockpit/EFIS/G1000/G1000PFD_2d.png`
* `cockpit/EFIS/G1000/G1000PFD_2d.png`

into your `X-Plane 11/Aircraft/<name>` directory. These files create a 1×1 pixel blank PNG that remove the bezel.

The default Windows border is still displayed across the top, however the size of the faceplate is designed to hide this. Double-click the window to maximize and hide the bar behind the faceplate.

Running unit

For more information, see [https://developer.x-plane.com/2017/09/three-lesser-known-aircraft-features-for-11-10/](https://developer.x-plane.com/2017/09/three-lesser-known-aircraft-features-for-11-10/).

## Make the G1000 audio panel

The G1000 audio panel is designed and built in the same way as the G1000 PFD and MFD panels. 

Laser cut the following from the same 5mm cast white acrylic material. You can use the pieces cut out for the PFD and MFD LCD panels:

* `laser_cut/audio-faceplate.svg`
* `laser_cut/audio-hardware-mount.svg`
* `laser_cut/audio-electronics-mount.svg`

Again, spray the audio faceplate with matt black paint, let it dry, then raster engrave the lettering and outlines from the *Engrave* layer in the `laser_cut/audio-faceplate.svg` file.

Engraving audio panel

Push fit the 7mm x 7mm momentary push button switches into the audio hardware mount, and again, use a small spot of glue on each side of the switch holds them in place. This approach removes the need for PCB for the button mounts.

Attach the Arduino Nano to the electronics mount, then use Weld-On or similar adhesive to attach the electronics mount at 90 degrees to the hardware mount, between the two columns of buttons.

Rear of audio panel with wiring and Arduino attached

To wrap up the hardware components, attach the dual-rotary encoder and 15mm momentary red push button switch. The dual rotary encoder doesn't actually get wired up, it's just for show.

The 3mm green LEDs attach to the back of the audio panel faceplate. Apply a small spot of glue on either side of the LED to hold it in place. When dry, use Weld-On or similar adhesive to attach the faceplate to the hardware layer. Take care as you feed the LED legs through the cut-outs in the hardware layer.

For wiring, run a common ground to all the 7mm x 7mm square buttons and the cathode (short leg) of each 3mm LED.

Each anode (long leg) of the LED requires a resistor, around 200-400 ohm depending on your LEDs and how bright you want them. You can also control the brightness in the Air Manager `.lua` file.

The following table outlines how I configured my pins and controls, but yours may vary:

| Type | Name | Pin |
|---|---|-----|
| Button | Transmit audio COM1 | A3 |
| LED | Transmit audio COM1 | D4 |
| Button | Monitor audio COM1 | A5 |
| LED | Monitor audio COM1 | D2 |
| Button | Transmit audio COM2 | A2 |
| LED | Transmit audio COM2 | D5 |
| Button | Monitor audio COM2 | A4 |
| LED | Monitor audio COM2 | D3 |
| Button | Monitor audio MKR | A1 |
| LED | Monitor audio MKR | D6 |
| Button | Monitor audio DME | A0 |
| LED | Monitor audio DME | D7 |
| Button | Monitor audio NAV1 | A11 |
| LED | Monitor audio NAV1 | D9 |
| Button | Monitor audio ADF | D13 |
| LED | Monitor audio ADF | D8 |
| Button | Monitor audio NAV2 | D12 |
| LED | Monitor audio NAV2 | D10 |
| Button | Big red display inversion | A1 |

## Completed G1000 suite

As I'm using a real Piper PA-28-151 cockpit, I removed the existing metal instrument panel traced the outline onto 3mm plywood. The outline was then cut, and then cut-outs made for where the G1000 units would go.

G1000 units mounted to instrument panel

There's quite a bit of wiring behind the panel when all completed.

Rear of G1000 units mounted to instrument panel

I used 90 degree adapters for the HDMI ports of the LCD driver boards to reduce cable clearance at the top when mounting into the cockpit also used left and right 90 degree USB cables for the PFD and MFD to again help with cable clearances. All three Arduinos connect to a powered USB hub.

Complete G1000 instrument panel mounted in cockpit

## Limitations and considerations

As I went through the build process and have spent some time using the G1000 suite, there's a few things to point out that I may have done differently or may not quite line up with real-world use.

The following are things to bear in mind for your own builds if there's a concern:

* The top row of the LCD screen is a little hard to read depending on your eye level.
    * I typically use COM2 and NAV2 so I can clearly see the frequencies.
* The buttons aren't rubber, to the tactile response is a little different.
* There's no backlighting, but I don't think it's really worth it here.
    * I've done this for some F-18 panels, and it was a lot of effort. You could try to find 7mm x 7mm square buttons that include an LED to fairly easily backlight those, but I don't know how well the 3D printed buttons would respond.
    * I'll likely run an LED strip at the top of the glare shield in the cockpit anyway, and if you weren't in an enclosed cockpit, ambient room lighting would likely be sufficient.
* The LEDs in the audio panel are bright.
    * The photos actually make it appear worse than they are, but larger resistors may have been better (I used 330 ohm resistors).
    * I could also drop the brightness to `0.5` or `0.25` in Air Manager.

## Frequently asked questions

A few common questions that people have asked or may come up:

### How long did it take to build this?

In total, about 6-8 weeks including designing the panels themselves. The final G1000 panel for my PFD ended up taking about one week as I knew exactly how to make, assemble, and wire everything up.

### How many prototypes were there?

I think my MFD was the third build. First build was just the laser cut panels to see how they fit and the LCD screen would look. Second build refined the panels and got as far as 7mm x 7mm buttons and attaching the layers together. By the third build, everything came together correctly and was wired up. The PFD was a straight single build. The audio panel took two builds.

### Why a glass cockpit in a steam-driven cockpit?

It is and it isn't. The actual fuselage is from a 1975 Piper PA-28-151. I originally started down the path of steam-driven gauges, but the engineering to build these myself, or the cost to purchase commerical flight sim gauges was just too much.

I did build functional Garmin GNS-430, Garnmin GNS-530, and GMS-340 units, which were the inspiration for this G1000 suite. So, I ended up switching from the AeroSphere Piper PA28-161 Warrior II v2 flight sim model in X-Plane 11 to the AeroSphere Piper PA-28-181 Archer III model.

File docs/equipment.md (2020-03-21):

# Equipment for building the flight sim

I use a mix of power tools and a cheap [Wen rotary tool](https://www.amazon.com/gp/product/B003BYRFH8) rather than an actual Dremel.

The main thing people ask about, especially for building the [Garmin G1000 suite](g1000.md) is what type of laser cutter and 3D printer I use. The answers are kinda boring, but shows what's possible with care and attention during the build.

## Laser cutter

Although I have access to a 60w Epilogue and a Universal laser cutter at the Garage at work, all of the current components (including the full [Garmin G1000 suite](g1000.md)) were cut on a cheap K40 laser in my own garage.

Sure, I may have gotten lucky, but I also knew enough from those other laser cutters to take my time in setting up the K40, aligning the mirrors carefully, and then understanding how to design parts and use a laser cutter. I've been very happy with the K40 laser.

Upgrade-wise, all I've done is to [3D-print a new bracket for fume extraction](https://www.thingiverse.com/thing:2809440), and [replace the blower motor](https://www.amazon.com/gp/product/B003EX02DA) for the extractor. It does a much better job with fumes now.

I also then use [K40 Whisperer](https://www.scorchworks.com/K40whisperer/k40whisperer.html) to process the jobs. I never even tried to install the crappy software that came with the unit.

## 3D printer

Like a laser cutter, a 3D printer has completely changed how I approach designing and building things.

I have a [Creality Ender 3](https://www.amazon.com/gp/product/B07BR3F9N6), which is a great balance of performance and budget. Take care, as there are some knock-offs. I had a problem with the control board shortly after I received the unit, but it was quickly diagosed and replaced under warranty by the authorized seller I'd used.

I did 3D-print a few upgrade parts such as a [fan guard](https://www.thingiverse.com/thing:2935204) and [filament guide](https://www.thingiverse.com/thing:2917932), but then similar to the K40 laser cutter, time and care went into assembling the printer, and it's worked out great.

I use a Raspbery Pi 3B+ running [Octoprint](https://octoprint.org/) to control 3D printing, and an old Logitech C270 webcam to monitor the status of print jobs.

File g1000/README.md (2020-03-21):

# Garmin G1000 suite for flight simulator

The supporting docs for building this Garmin G1000 suite is at [https://fouldsy.github.io/piper-pa-28-flight-sim/g1000.html](https://fouldsy.github.io/piper-pa-28-flight-sim/g1000.html)

Finished G1000 instrument panel

Close-up G1000 instrument panel

Complete G1000 instrument panel

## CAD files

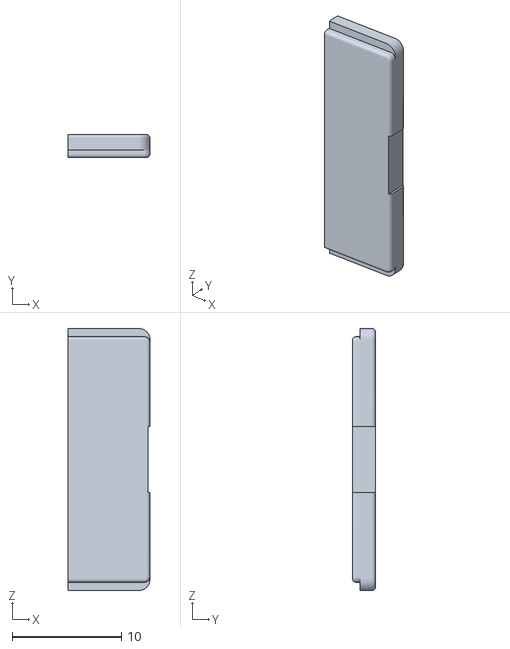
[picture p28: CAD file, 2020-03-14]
g1000/3d_print/dummy_sd_card.stl
7.50 x 2.10 x 24.0

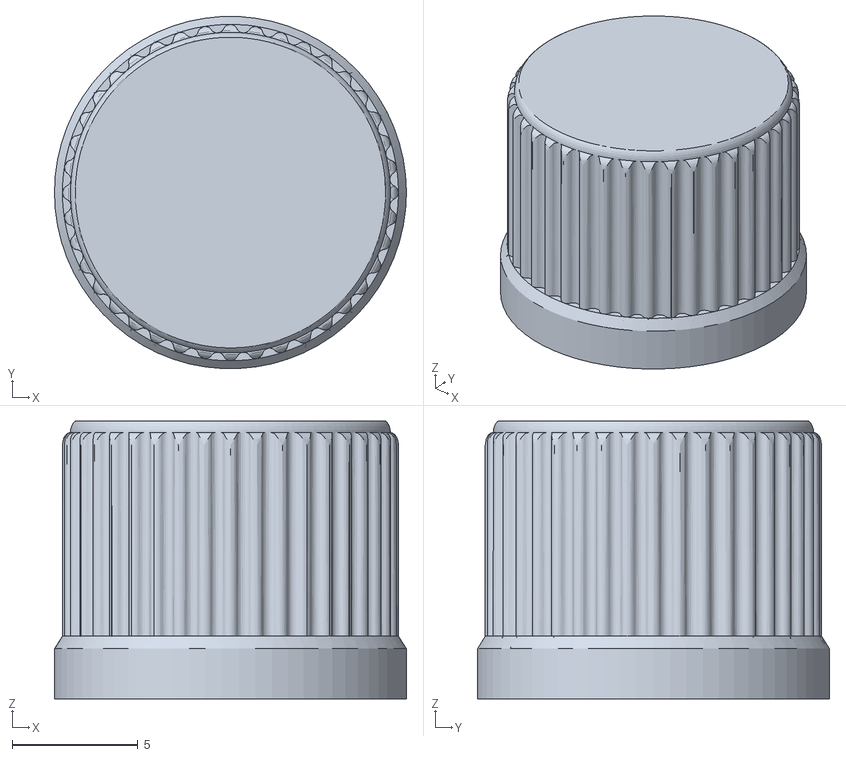
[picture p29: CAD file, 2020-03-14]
g1000/3d_print/knob_heading.stl
14.0 x 14.0 x 11.1

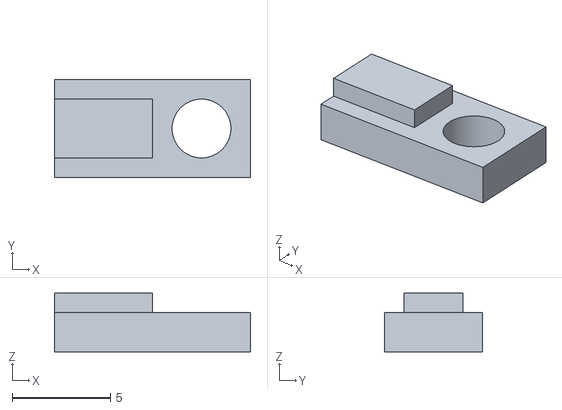
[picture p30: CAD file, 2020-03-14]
g1000/3d_print/screen_clips_1mm.stl
10.0 x 5.00 x 3.00

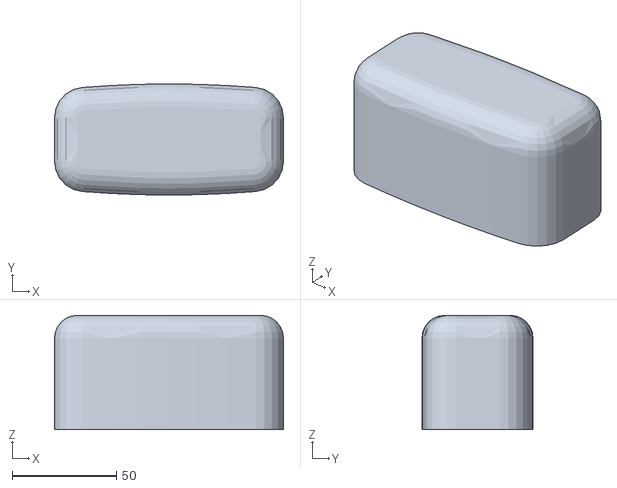
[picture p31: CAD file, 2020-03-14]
g1000/3d_print/button_small.stl
110.1 x 53.4 x 55.0

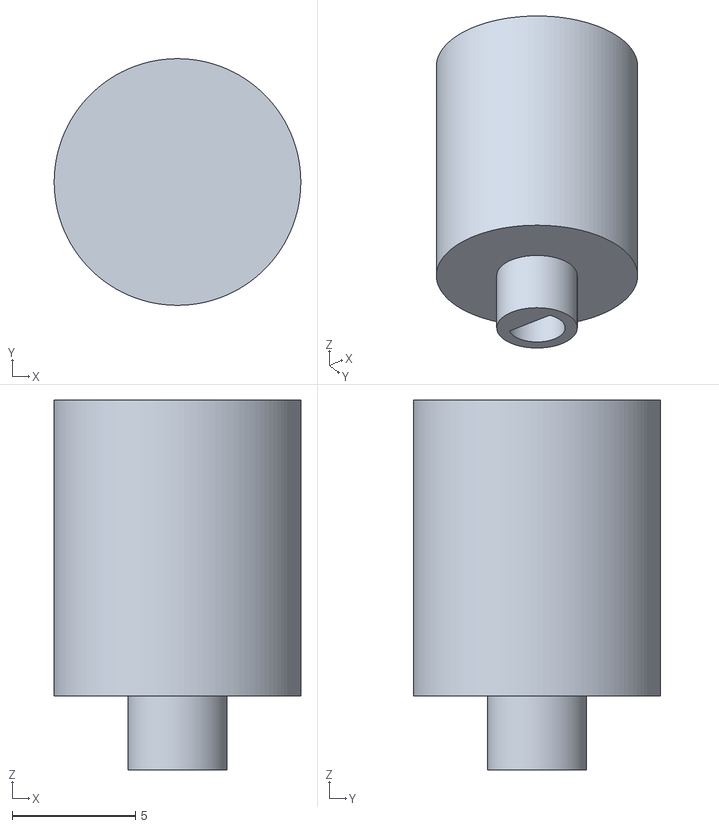
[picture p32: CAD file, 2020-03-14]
g1000/3d_print/knob_range_pan.stl
10.0 x 10.0 x 15.0

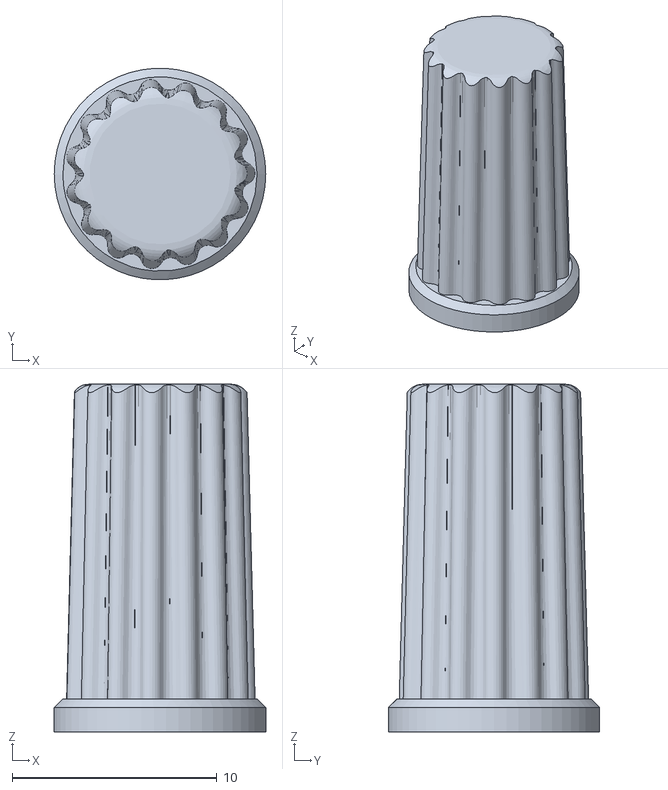
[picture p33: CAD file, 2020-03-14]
g1000/3d_print/knob_volume.stl
10.3 x 10.3 x 17.0

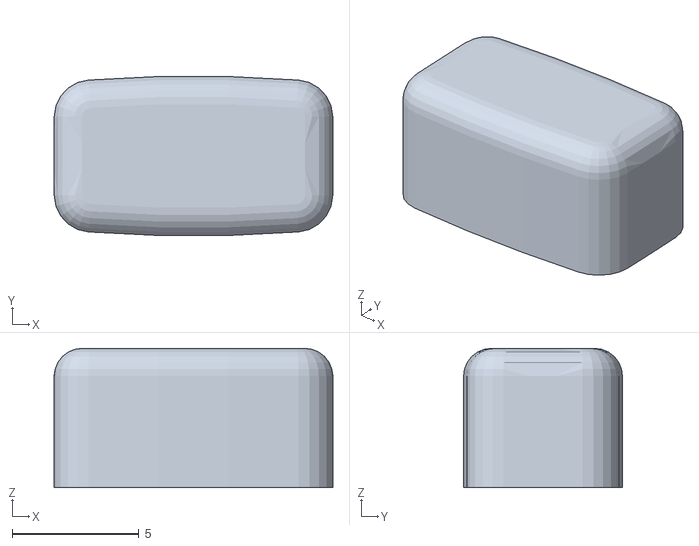
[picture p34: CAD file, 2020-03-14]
g1000/3d_print/button_medium.stl
11.0 x 6.28 x 5.50

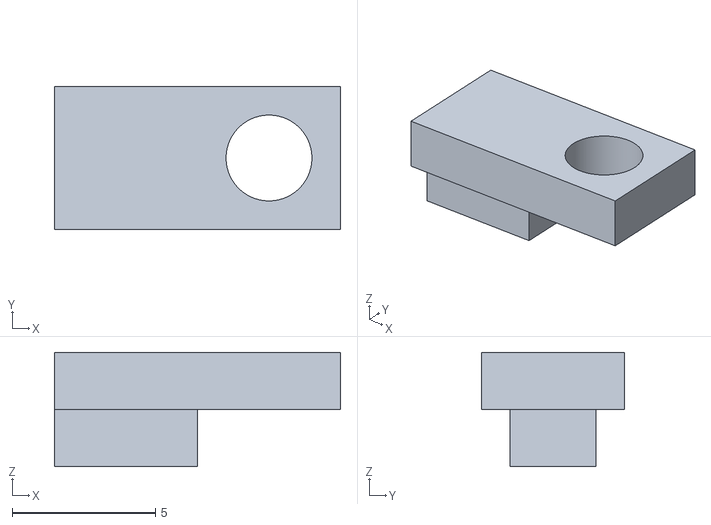
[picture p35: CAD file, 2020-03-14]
g1000/3d_print/screen_clips.stl
10.0 x 5.00 x 4.00

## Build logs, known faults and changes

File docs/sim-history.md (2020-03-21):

# Flight simulator cockpit history

The first flight sim experience I can recall was on my dad's Macintosh SE/30 in the early 1990s. I honestly don't know what version of Flight Sim this would have been, but from 1995, we had a Windows-based PC (Packard Bell), and I was using Microsoft Flight Simulator 5.1.

I moved through Flight Simulator for Windows 95, Flight Sim 98, Flight Sim 2000, and Flight Sim 2002. I miss the Microsoft Sidewinder Force Feedback joysticks! I also remember playing a multitude of the Janes flight sims, along with the Microsoft Combat Flight Simualtor series.

## First home cockpit build 
In 2005, I was getting ready to move to Alaska. I got heaily into Microsoft Flight Simulator 2004: A Century of Flight. After I moved in 2006, I got the CH Products yoke and rudder pedals, the first step beyond just a joystick. This was probably what I could call v1 of my home cockpits.

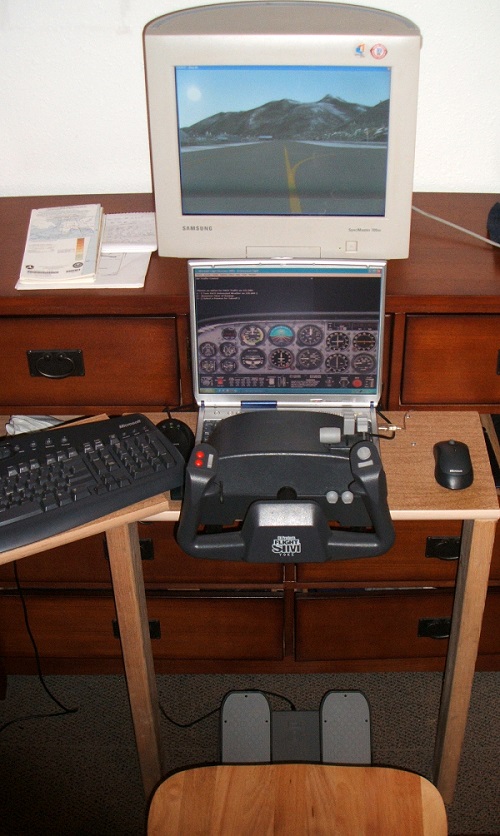
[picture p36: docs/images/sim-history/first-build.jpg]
Initial home cockpit in Alaska, circa 2006-2007


I often did 3-4hr flights in the PMDG 737-800 on routes like Anchorage -> Seattle on that wooden chair...

## Second home cockpit build - panels

By early 2008, I was looking at building panels. With only a single-speed power drill and almost nothing by way of real tools, I used some Desktop Aviator USB interface boards to build what would be v2 of my home cockpits.

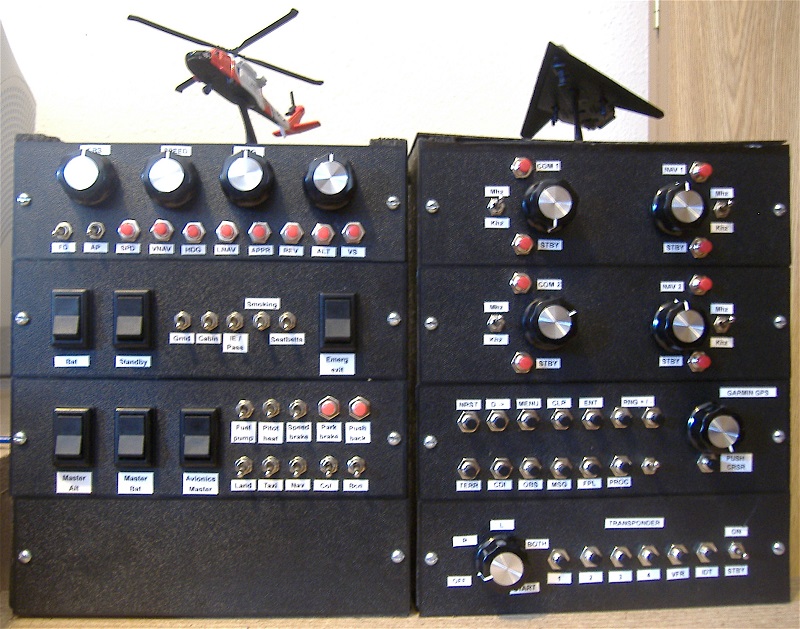
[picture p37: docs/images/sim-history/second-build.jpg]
First cockpit panels using Desktop Aviator USB interface boards


These panels were a combination of wanting to do GA aircraft and passenger jets. Note the Garmin GPS unit - an LCD screen just wasn't really an option then. My co-pilot at the time also left a lot to be desired.

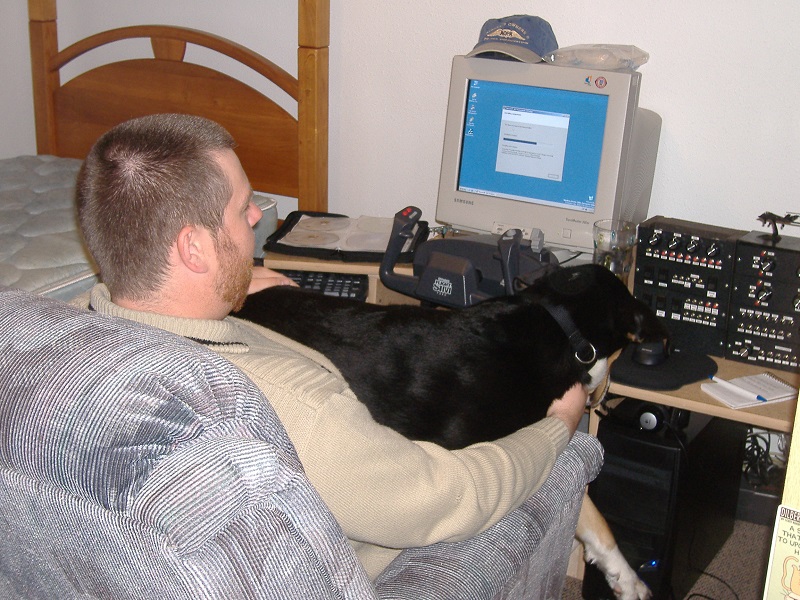
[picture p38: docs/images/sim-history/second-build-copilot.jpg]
My copilot during the second home cockpit


## Third home cockpit build - refined panels and radio LCDs

After moving to St. Louis, I re-thought my approach to panels. Still using Desktop Aviator USB interface cards, but now also using Arduinos and link2fs to drive LCD screens, along with profesionally cut metal panels.

This build worked well, and the LCDs for the radio panels definitely added a lot of immersion. I used this set up for a number of years, technically v3 of the home cockpits.

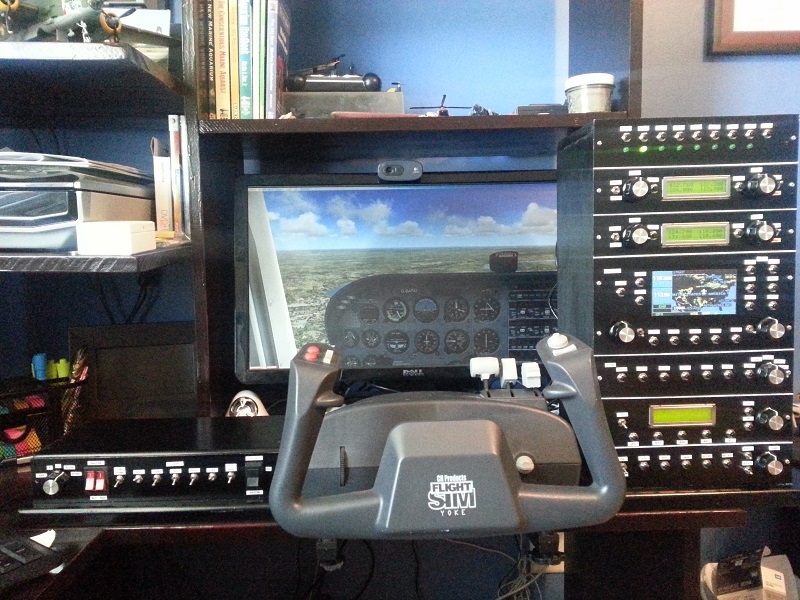
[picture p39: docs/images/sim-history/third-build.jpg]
Refined panels using Desktop Aviator USB interface boards and Arduinos for radio LCD screens


The GPS unit is using just a printed piece of card with a dummy Garmin 500 unit image, as still LCD screens were tough to find for that size and resolution to fit into the available space.

## VR and beyond

By 2017 and 2018 I was moving into VR with an Oculus Rift which added incredible immersion, but sacrificed resolution for reading instruments, along with lack of tactile feel for hardware control and panels.

I do still really enjoy VR for DCS: World, as for military jets, the immersion is incredible. For GA aircraft in flight simulator, my only real option was to finally step up to an actual cockpit, which is where I'm at now.

Yes, an actual cockpit as an extravagance. But, after briefly taking some flying lessons in a Cessna 152 out of Merrill Field, Anchorage, I've always felt lacking in immersion compared to the real thing. Basing a flight sim out of a real cockpit adds immediate immersion, especially with the 12ft diameter 180 degree curved screen. To me, it's worth it.

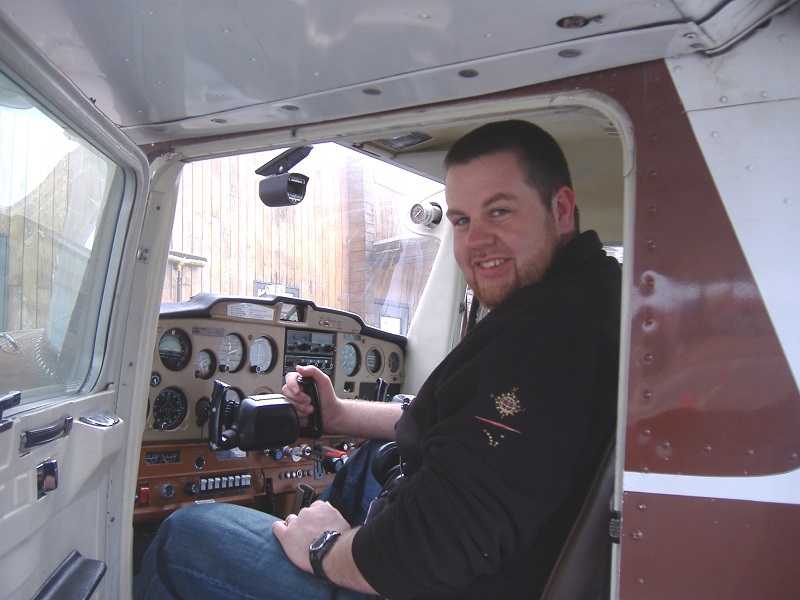
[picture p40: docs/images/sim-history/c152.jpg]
In the cockpit of a Cessna 152 in Merrill Field, Anchorage


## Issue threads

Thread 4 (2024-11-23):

Interfacing with the rotary switch

johnkwaters, 2024-11-23:
Hi,
I am using the same rotary switch and 3d printed component as you to create a fuel selector for my PA-28 in X-Plane. I have hooked up the switch to a board from Desktop Aviator (2040). It interfaces via USB and in X-Plane I can now detect the 1 and 2 positions, but for the PA-28 those would be Right and Off. The Left tank position is 0, which is straight up - the middle rotary switch position, and this one give 0 voltage - so how do I detect that condition so I can connect it to fuel tank left?

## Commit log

2019-08-24 Adding switch panel logic
2020-03-14 Initial G1000 suite commit and docs
    [button_medium.stl, button_small.stl, dummy_sd_card.stl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]
2020-09-25 Add audio panel pin wiring
2020-11-27 Updated README with current controls status
